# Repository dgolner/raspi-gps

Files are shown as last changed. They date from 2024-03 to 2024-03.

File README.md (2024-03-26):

English ∙ [Hrvatski](README-hr.md)

# raspi-gps

This simple project **raspi-gps** is a small GPS tracking system I made using Raspberry Pi and an external GPS Bluetooth module. This device is conceived as offline tracking, just connect it to a USB in the car, turn it on and record movement without connecting to the Internet. Since the movement (change of GPS position in time) is recorded in the form of GPX files on the SD card, it's possible to load such routes in external applications such as Google Earth by downloading from the SD card.

The project seemed interesting to me to share, so I created this tutorial.

## Contents of the project and tutorial

- [Motivation for this project](#motivation-for-this-project)
- [Components](#components)
- [Initial configuration of Raspberry Pi](#initial-configuration-of-raspberry-pi)
- [Raspberry Pi pairing and connecting to Bluetooth GPS module](#raspberry-pi-pairing-and-connecting-to-bluetooth-gps-module)
- [Python communication with Bluetooth GPS module](#python-communication-with-bluetooth-gps-module)
- [GPS codes](#gps-codes)
- [How to create a GPX file](#how-to-create-a-gpx-file)
- [Start a Python script automatically](#start-a-python-script-automatically)
- [Using button and RGB LED](#using-button-and-rgb-led)
- [Python code completion](#python-code-completion)
- [Project in practice](#project-in-practice)
- [Off-topic simplification with fewer components](#off-topic-simplification-with-fewer-components)
- [References](#references)

## Motivation for this project

Raspberry Pi is cool for personal projects and researching what can it do, so after some projects I did with Arduino, I went to something more powerful and more serious. Especially when it starts to think of gadgets that will use Wi-Fi with Bluetooth and program it in Python. From previously collected components in drawers, why not use what I have? I specifically have an old Raspberry Pi Zero W, an even older external GPS device, some electronic components from the starter kits and the idea.

I wanted to make a GPS tracker, but a little different one. The GPS module is not a classic Raspberry Pi component that connects to Raspberry pins. It's an external module with a battery and I can put it in a place where the GPS signal is stronger. That is why there are some advantages over GPS and tracking through cell phones and some special apps. So Raspberry Pi just connects to a USB or Power Bank, merges with GPS, finds visible satellites and starts tracking the position. It's a good idea to save routes on weekend rides. Online monitoring of such a route or current position can only be an upgrade over this project one day.

## Components

For this project, I'll use a Raspberry Pi Zero W just because I have it from before and it's compact enough for me. Any Raspberry that supports Wi-Fi and Bluetooth can be used. Wi-Fi is essential for connection to the PC, configuring, uploading Python code and downloading files from the SD card.

Bluetooth is used to connect to the external GPS module. In my case, I use ancient Haicom HI-406BT, so it's good to keep track of that mark in the tutorial in the part that refers to Bluetooth connection and communication. Almost every standalone Bluetooth GPS device that supports serial communication and NMEA data will serve a purpose. It doesn't matter if it's a premium model (I didn't try Garmin GLO 2 since it's too expensive for my needs) or some cheap noname (an even better option), it's important to find some that can be connected to PC, mobile phone or something third that supports Bluetooth, can pair and support serial communication. Support for Galileo or GLONASS doesn't matter, GPS support is essential, and for easier check of your device just see if it contains at least a SiRF StarIII chip.

Not necessary, but a Power Bank can be connected to Raspberry's USB port if it will not be suited otherwise, eg through USB in the car. Of the other components, there are some resistors, DuPont wires, connectors, a button, RGB LED and a small experimental breadboard, all for the compactness of the solution. The resistors are there for protection and can be of other resistance, not too big and will work OK.

 Components are listed in the table:

| **Used components** |
|---|
| 1x Raspberry Pi Zero W |
| 1x external Bluetooth GPS module |
| 1x powerbank |
| 1x mini breadboard |
| 1x button |
| 1x RGB LED |
| 1x 1 kΩ resistor |
| 2x 10 kΩ resistor |
| pin connectors and DuPont wires |

For the project, I used an RGB LED with a common anode (+ pole), which made it difficult for me to program, but that's the RGB LED that I had. Programming is easier with an LED with a common cathode (- pole). It's easier because the colors are turned on by releasing electricity on each pin in charge of color, for example, high on the red and low on others results only in the red color of the LED. When the LED has a common anode (+), colors are turned on by shutting down the current (sending low on pins), so it's inverted. For example, for red color, it means low on the pin for red and high on the others. If you have an RGB LED that is not like in my case, feel free to play a little for the results.

How the components are first drawn and interconnected on the diagram:

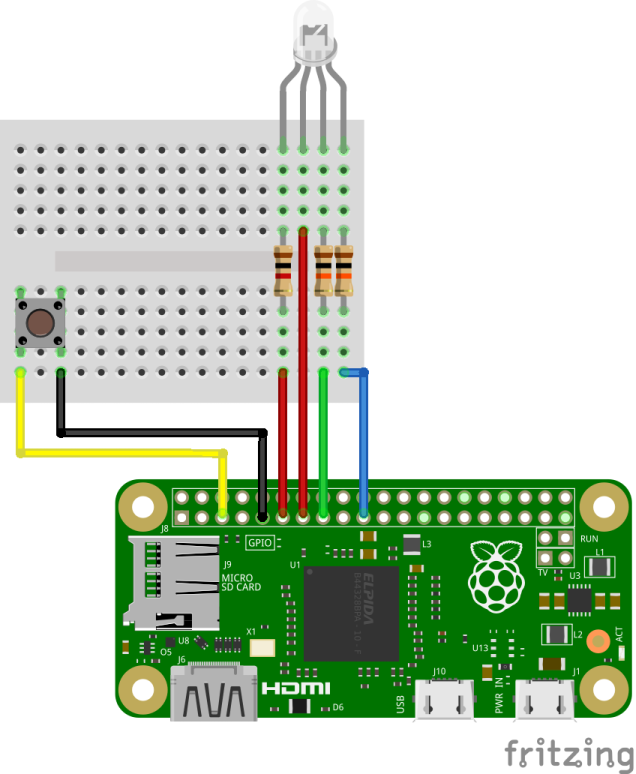
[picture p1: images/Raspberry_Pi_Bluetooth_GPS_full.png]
Fritzing diagram - Raspberry Pi Zero W with components


I use a 1 kΩ resistor on the red pin of the RGB LED while I use 10 kΩ resistors on the others. There is a resistor of lower value on the red to get better light intensity but feel free to play with the combinations of resistors.

This is how the components are connected in the project while still on the table:

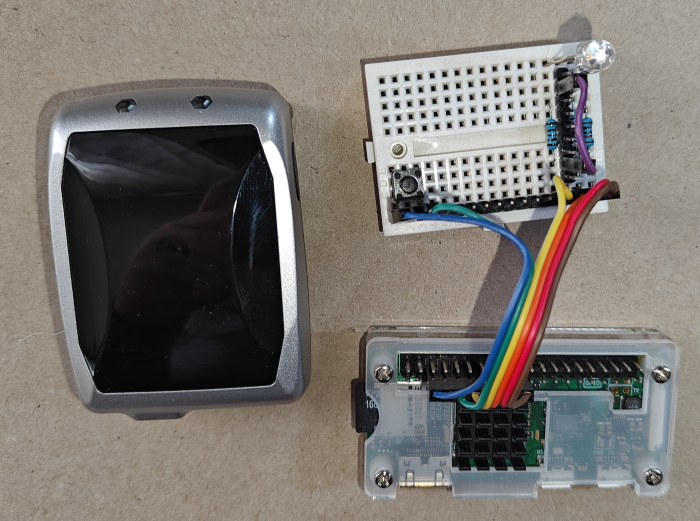
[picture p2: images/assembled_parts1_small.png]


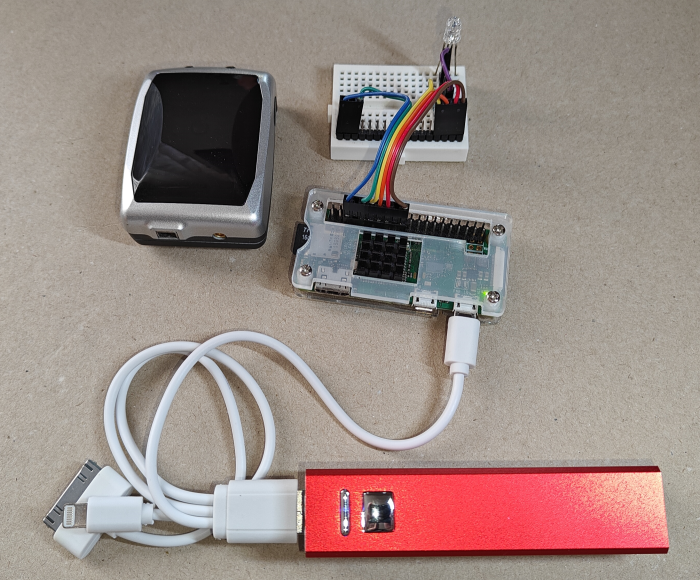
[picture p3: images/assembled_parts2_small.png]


After configuring, uploading Python code, local testing and packaging into a small case this is how my project looks in the car connected to a USB and the GPS device is located under the rear glass for a better reception of the satellites:

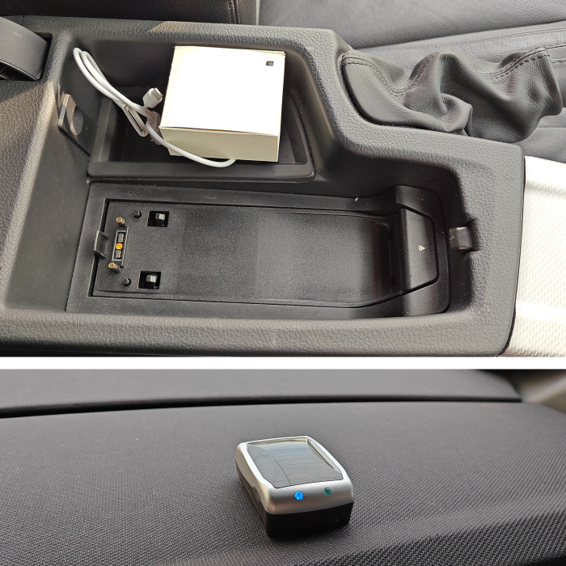
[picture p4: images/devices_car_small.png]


I made a cardboard mini case, so it can be downloaded, printed and cut, and fits the dimensions of the components I used.

[](/resources/RasPiGPS_cardboard.pdf)

Once the components are connected, it's necessary to configure the Raspberry Pi before programming.

## Initial configuration of Raspberry Pi

The Raspberry Pi OS has to be installed on the Raspberry Pi that will be used, I installed it over the Raspberry Pi Imager earlier, so it's not covered in this tutorial. It was also created when installing a **pi** user with a password. I don't use Raspberry when it's connected to the monitor, I configured it in headless mode. This can only complicate the work at first. It's important to configure which Wi-Fi network it connects to and which will be a fixed IP address.

To connect to Raspberry over the home Wi-Fi network, it's necessary on its SD card in the root directory to create an empty file **ssh** without extension:



Also on the SD card in the root directory create a file with the exact name **wpa_supplicant.conf** in which the Wi-Fi connection data will be stored. The contents of the file itself should be:
```sh
country=YOUR_COUNTRY_CODE
ctrl_interface=DIR=/var/run/wpa_supplicant GROUP=netdev
update_config=1
network={
    ssid="YOUR_WIFI_SSID"
    psk="YOUR_WIFI_PASSWORD"
    key_mgmt=WPA-PSK
}
```

Under **YOUR_COUNTRY_CODE** put your country code (eg us), under **YOUR_WIFI_SSID** put SSID of home Wi-Fi and in **YOUR_WIFI_PASSWORD** put your network password. It's obvious here that security is not at a high level, but at least Raspberry will connect automatically to the network after boot. The next thing after booting is finding its IP address, which can be found most often by connecting and checking on a home router.

The next step is to connect through its IP address using **Putty**, simply entering the SSH connection with the IP address of Raspberry Pi and when requested enter username and password. After connecting, you'll get the shell:

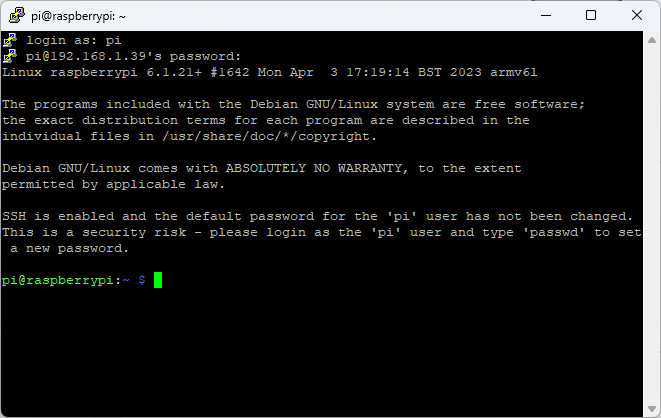
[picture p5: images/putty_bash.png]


From the shell, launch the configuration of Raspberry Pi OS:
```sh
sudo raspi-config
```

The Configuration Tool screen is obtained and be sure to set an autologin with user **pi** (set default user) for later automatic launch of the Python script of this project:

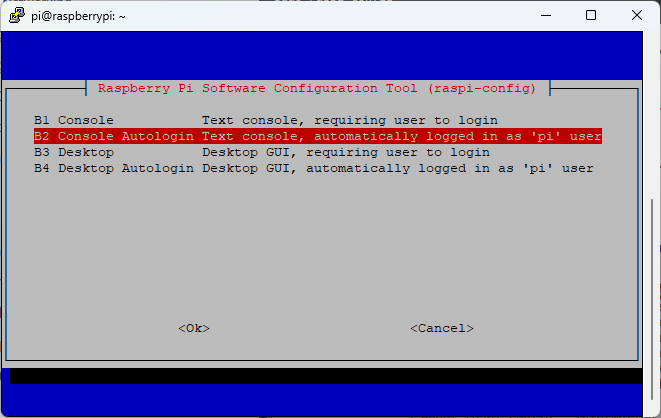
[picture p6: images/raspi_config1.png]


Also, be sure to enable SSH Server:

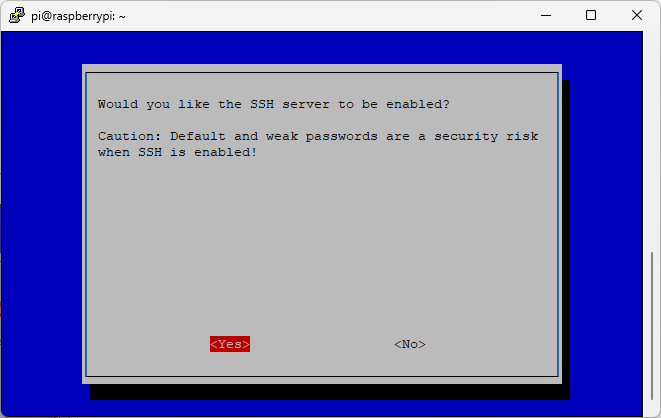
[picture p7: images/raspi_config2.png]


After leaving the raspi-config, it's necessary to set a static IP address so we don't have to look for it each time Raspberry connects to the router. For this, edit the file **/etc/dhcpcd.conf**, from various shell editors, I mostly use **pico**:
```sh
pico /etc/dhcpcd.conf
```

In the file, you need to locate the section where the static IP address is configured. Initially, all lines in the file are commented out with **#**. Uncomment the lines, following the example, and modify them according to your router’s address and the desired fixed IP address:
```sh
# Example static IP configuration:
interface eth0
static ip_address=<YOUR_RASPBERRY_IP>/24
#static ip6_address=fd51:42f8:caae:d92e::ff/64
static routers=<YOUR_ROUTER_IP>
static domain_name_servers=<YOUR_ROUTER_IP> 8.8.8.8
```
Replace **<YOUR_RASPBERRY_IP>** with the desired fixed address. It can even be the one under which the Raspberry initially connected to the router automatically. Replace **<YOUR_ROUTER_IP>** with the router’s IP address, such as 192.168.0.1 (which remains unchanged). Save the changes and exit the editor.

After making the changes, restart the Raspberry:
```sh
sudo shutdown -r now
```

To upload and download files (Python code, GPX files) on the Raspberry’s SD card while it’s connected to the network, it’s best and most practical to use the FTP protocol along with a free client like FileZilla. To achieve this, follow these steps for installing the FTP server from the shell:
```sh
sudo apt install vsftpd
```

After installation, proceed with configuring the FTP server by editing the file **/etc/vsftpd.conf**:
```sh
sudo pico /etc/vsftpd.conf
```

In the file, when you find these commented lines, uncomment them by removing the **#**
```sh
#write_enable=YES
#local_umask=022
#anon_upload_enable=YES
```

At the end of the file add the following lines:
```sh
user_sub_token=$USER
local_root=/home/$USER/FTP
```

Save changes, exit the editor and from shell create FTP shared directory **FTP/share** in your user home directory and add all rights to users:
```sh
mkdir -p /home/pi/FTP/share
chmod 777 /home/pi/FTP/share
```

Restart FTP daemon:
```sh
sudo service vsftpd restart
```

If everything is successful, you can connect to your Raspberry with an FTP client.

## Raspberry Pi pairing and connecting to Bluetooth GPS module

After the initial configuration, the GPS module checking and pairing with Raspberry Pi is followed and this step is crucial for going on. In the booting sequence of the Raspberry, Bluetooth service is also being launched, so the service status can be checked through the shell command:
```sh
systemctl status bluetooth
```

An active Bluetooth service is expected as in this example:
```sh
● bluetooth.service - Bluetooth service
     Loaded: loaded (/lib/systemd/system/bluetooth.service; enabled; vendor pre>
     Active: active (running) since Mon 2023-11-06 20:23:24 CET; 6 days ago
       Docs: man:bluetoothd(8)
   Main PID: 451 (bluetoothd)
     Status: "Running"
      Tasks: 1 (limit: 724)
        CPU: 327ms
     CGroup: /system.slice/bluetooth.service
             └─451 /usr/libexec/bluetooth/bluetoothd
```

After we checked and confirmed that the service is active now, it's necessary to start scanning for Bluetooth devices nearby. Of course, an external Bluetooth GPS device must be turned on. Finding devices nearby from the shell:
```sh
hcitool scan
```

The result of scanning should be a list of visible Bluetooth devices with their addresses and names, eg:
```sh
pi@raspberrypi:~ $ hcitool scan
Scanning ...
        00:02:78:19:70:30       HI-406BT
        4C:31:2D:73:88:88       MiTV-AYFR0
```

The use of **hcitool** is optional (it's good for control) because I'll continue with interactive tool **bluetoothctl** for pairing and scanning from the shell:
```sh
bluetoothctl
```

After starting, his interactive shell will appear through which the devices are managed:
```sh
Agent registered
[CHG] Controller B8:27:EB:F6:C0:3F Pairable: yes
[bluetooth]#
```

First "power on" Bluetooth from the tool:
```sh
[bluetooth]# power on
Changing power on succeeded
```

Register its agent:
```sh
[bluetooth]# agent on
Agent is already registered
```

Switch to a default agent:
```sh
[bluetooth]# default-agent
Default agent request successful
```

The previous steps were "fire and forget" because I just relied on the methods that surely worked. This is followed by scanning of the surrounding devices and monitoring what will appear as results (visible also through the previous use of **hcitool**):
```sh
[bluetooth]# scan on
Discovery started
[CHG] Controller B8:27:EB:F6:C0:3F Discovering: yes
[NEW] Device DB:93:F3:DA:E4:C0 vívoactive3
[NEW] Device 00:02:78:19:70:30 00-02-78-19-70-30
[CHG] Device 00:02:78:19:70:30 LegacyPairing: no
[CHG] Device 00:02:78:19:70:30 Name: HI-406BT
[CHG] Device 00:02:78:19:70:30 Alias: HI-406BT
[CHG] Device 00:02:78:19:70:30 LegacyPairing: yes
```

From the upper result, it's necessary to find the address of the Bluetooth GPS module according to its name and it's good to remember since it will be used several times throughout the tutorial. It's crucial to detect which GPS module you use since each is different. In my example from the components I used, I found 00:02:78:19:70:30 which corresponds to the name HI-406BT. So, in your case, find which address matches your device and pair it with the command **pair** followed by the address, this is my example:
```sh
[bluetooth]# pair 00:02:78:19:70:30
Attempting to pair with 00:02:78:19:70:30
[CHG] Device 00:02:78:19:70:30 Connected: yes
Request PIN code
[agent] Enter PIN code: 0000
[DEL] Device DB:93:F3:DA:E4:C0 vívoactive3
[CHG] Device 00:02:78:19:70:30 UUIDs: 00001101-0000-1000-8000-00805f9b34fb
[CHG] Device 00:02:78:19:70:30 ServicesResolved: yes
[CHG] Device 00:02:78:19:70:30 Paired: yes
Pairing successful
[CHG] Device 00:02:78:19:70:30 ServicesResolved: no
[CHG] Device 00:02:78:19:70:30 Connected: no
```

Immediately after attempting to pair, as seen above, you will need to enter your **PIN** pairing code, my example and a lot of them by default have **0000**. If everything has passed successfully you will see the message **Pairing successful**. When pairing, it's also possible to get this type of error:
```sh
[bluetooth]# pair 00:02:78:19:70:30
Attempting to pair with 00:02:78:19:70:30
Failed to pair: org.bluez.Error.AlreadyExists
```

> :warning: In this case, the most common problem is that the device is already connected to something and in use, so it needs to be disconnected from this other device. After that, repeat the upper steps. If that doesn't help, restarting of the Bluetooth service could help.

If everything has gone through so far, it's possible to get info about the device and status according to its address:
```sh
[bluetooth]# info 00:02:78:19:70:30
Device 00:02:78:19:70:30 (public)
        Name: HI-406BT
        Alias: HI-406BT
        Class: 0x00001f00
        Paired: yes
        Trusted: no
        Blocked: no
        Connected: no
        LegacyPairing: yes
        UUID: Serial Port               (00001101-0000-1000-8000-00805f9b34fb)
        RSSI: -35
```

Furthermore, all paired devices can be seen, most important is to see the GPS module that will be used in the project:
```sh
[bluetooth]# paired-devices
Device 00:02:78:19:70:30 HI-406BT
```

Finally, since everything went OK, you should exit from the **bluetoothctl** tool because it will no longer be needed:
```sh
[bluetooth]# exit
```

The next step is tool **rfcomm** also used in Bluetooth configuration through shell:
```sh
rfcomm
```

The result will be the address and status of **RFCOMM** channels to which the Bluetooth device is connected as my example:
```sh
rfcomm1: 00:02:78:19:70:30 channel 1 closed
```

It's important to remember the results from **rfcomm1** as it will be used below as part of the command. To connect to the device from the shell, it's necessary to combine **/dev/rfcomm1** and the address of the device from the previous steps:
```sh
rfcomm bind /dev/rfcomm1 00:02:78:19:70:30
```

> :warning:  If you have no rights, the following error will appear:

**Can't create device: Operation not permitted**

The solution is to use **sudo** to call the command:
```sh
sudo rfcomm bind /dev/rfcomm1 00:02:78:19:70:30
```

If we have successfully done all of these steps so far, which means we have already paired the device and we use it, we will get the following message that means everything is OK:
**Can't create device: Address already in use**

It looks like a warning or an error, but it's the result of the previous tools that are used. Later, that binding through **rfcomm1** will be used in Python scripts.

## Python communication with Bluetooth GPS module

It's time to write the first Python program that will communicate with the Bluetooth GPS module. The minimum version of Python should be 3.5, in my case it was used 3.9.2, but it's always good to use the higher version. Since communication through Bluetooth is a serial, first from shell check if there is a Python library **pyserial** that will be used:
```sh
pip3 list | grep pyserial
```

If the upper check doesn't return that the library exists, you should install it (if it shows an error with permissions, switch to **pi** user with **su pi**):
```sh
pip3 install pyserial
```

Now create a new Python file named **raspi-gps.py** that will read serial communication and print as meaningfully as possible. The serial communication reads data from the port located on device **/dev/rfcomm1** which corresponds to the previous chapter. It's important to know that this port will be further used, and the steps for connecting to Bluetooth from the previous chapter are also important. For this first script, it's mandatory to first connect to the GPS module before starting (see previous use of **rfcomm bind**). In an infinite loop, the script is trying to read character by character from the serial port until **'\r'** is found and then, that message is printed. Source code of this first iteration of connecting to the GPS module and serial communication:
```python
import serial

sr = serial.Serial('/dev/rfcomm1', timeout=2)
line = ''

while True:
  chr = sr.read().decode('utf-8')
  if chr == '\r':
    print(line)
    line = ''
  else:
    line = line + chr
```

After a short study of the source code, run it from the shell:
```sh
python3 raspi-gps.py
```

If everything went OK from the previous steps and there were no errors when running the Python script, the cryptic lines similar to my example should soon appear:
```sh
$GPVTG,202.93,T,,M,0.05,N,0.1,K,N*0C

$GPGGA,165941.553,4553.9397,N,01650.9875,E,1,03,2.6,-41.4,M,41.4,M,,0000*49

$GPRMC,165941.553,A,4553.9397,N,01650.9875,E,0.10,216.49,130923,,,A*62

$GPVTG,216.49,T,,M,0.10,N,0.2,K,N*09

$GPGGA,165942.553,4553.9396,N,01650.9875,E,1,03,2.6,-41.4,M,41.4,M,,0000*4B

$GPRMC,165942.553,A,4553.9396,N,01650.9875,E,0.09,252.51,130923,,,A*61

$GPVTG,252.51,T,,M,0.09,N,0.2,K,N*08

$GPGGA,165943.553,4553.9396,N,01650.9874,E,1,03,2.6,-41.4,M,41.4,M,,0000*4B

$GPRMC,165943.553,A,4553.9396,N,01650.9874,E,0.10,215.45,130923,,,A*6F

$GPVTG,215.45,T,,M,0.10,N,0.2,K,N*06
```

This looks completely correct and it's **NMEA** data coming from communication with the GPS module. Further, we'll deal with deciphering these data.

If an error occurs after starting this script and it's related to binding to the GPS module and is also visible as a Python exception, it means that it's necessary to restart the binding before starting this script from the shell. As in the previous steps you must run **rfcomm bind** with the device address (I'll continue to use **<YOUR_BLUETOOTH_MAC_ADDRESS>**) and check the status:
```sh
sudo rfcomm bind /dev/rfcomm1 <YOUR_BLUETOOTH_MAC_ADDRESS>
rfcomm
```

In order not to have to repeat the binding at each launch of Raspberry Pi and check the status before the start of a Python script, I added a call for binding immediately in the script. It will execute the binding by calling an OS command at each start of this script:
```python
import os
import serial
import sys
import time

try:
  fp = os.popen('sudo rfcomm bind /dev/rfcomm1 <YOUR_BLUETOOTH_MAC_ADDRESS>')
  time.sleep(2)
  fp.close()
except:
  print(sys.exc_info())
  sys.exit(1)

try:
  sr = serial.Serial('/dev/rfcomm1', timeout=2)
except:
  sys.exit(1)

line = ''

while True:
  try:
    chr = sr.read().decode('utf-8')
    if chr == '\r':
      print(line)
      line = ''
    else:
      line = line + chr
  except:      
    sys.exit(1)
```

Run again from the shell:
```sh
python3 raspi-gps.py
```

The result should be the same, the **NMEA** data of the GPS module will appear and less should be taken care of connecting to the module, it's enough to turn it on and after that, you can run the Python script that will begin to communicate with it.

## GPS codes

**NMEA** (National Marine Electronics Association) is as it says an association, and for is important **NMEA-0183** communication specification primarily intended for nautical electronics. Most importantly, it's used as a standard for communication with GPS devices. External GPS devices receive signals from visible satellites and form NMEA data that transmit further as in our case via Bluetooth serial communication. The data contain the talker ID (GPS, Galileo, GLONASS, BeiDou), message group and the data that correspond to the group. Details of the groups and message content with field descriptions are available in the link [NMEA Sentences](https://receiverhelp.trimble.com/alloy-gnss/en-us/NMEA-0183messages_MessageOverview.html).

Any message that is received (NMEA sentence) begins with **$** and talker ID, from the above example comes **$GP** which is a label for **GPS**. If your GPS module supports other systems, you could also get the start of a message for example with $GA as Galileo. I'll focus on GPS so I'll decode messages that start with **$GP**. After the talker ID comes the message group, and for this project, the most important are the **GGA - Global Positioning System Fix Data** and **VTG - Track made good and Ground speed**. GGA data contain various fields that are important to me: latitude, longitude, elevation and orientation, I won't use others. VTG is interesting to me just for reading the speed, I don't use the rest.

I extracted the necessary information according to the group and filed position in the message, it helped me NMEA documentation, and further, all that matters is the presentation of the data. There is a challenge with the value of the latitude and longitude because their values are slightly different from expectations, so it's necessary to convert from NMEA formatted data (format is (d)ddmm.mmmm where **d** stands for degrees, and **m** stands for minutes) to decimal format. I used a little help from an article on [Stack Overflow](https://stackoverflow.com/questions/36254363/how-to-convert-latitude-and-longitude-of-nmea-format-data-to-decimal) so I also created a conversion function in my Python code.

I've upgraded the upper Python code for reading the NMEA data. Every message that is read from GPS, regarding NMEA codes is extracted and checked if it contains the necessary GGA and VTG groups and the necessary values in them. To display the position, I additionally convert values to degrees and add the orientation. So upgraded and beautified Python source code looks now like this:
```python
import math
import os
import serial
import sys
import time

def nmeaToDeg(v):
  y, x = math.modf(v / 100)
  y = (y * 10) / 6
  return x + y

try:
  fp = os.popen('sudo rfcomm bind /dev/rfcomm1 <YOUR_BLUETOOTH_MAC_ADDRESS>')
  time.sleep(2)
  fp.close()
except:
  print(sys.exc_info())
  sys.exit(1)

try:
  sr = serial.Serial('/dev/rfcomm1', timeout=2)
except:
  sys.exit(1)

line = ''

while True:
  try:
    chr = sr.read().decode('utf-8')
    if chr == '\r':
      parts = line.replace('\n', '').split(',')

      try:
        # GGA - Global Positioning System Fix Data
        if parts[0] == '$GPGGA':
          latitude = nmeaToDeg(float(parts[2]))
          latitudeDirection = parts[3]
          longitude = nmeaToDeg(float(parts[4]))
          longitudeDirection = parts[5]
          print('Latitude / longitude: %s %s, %s %s' % 
            (latitude, latitudeDirection, longitude, longitudeDirection))
          elevation = float(parts[9])
          print('Elevation: %s m' % (elevation))

        # VTG - Track made good and Ground speed
        if parts[0] == '$GPVTG':
          speed = float(parts[7])
          print('Speed: %s km/h' % (speed))
      except:
        None

      line = ''
    else:
      line = line + chr
  except:
    print(sys.exc_info())
    sys.exit(1)
```

Run again from the shell:
```sh
python3 raspi-gps.py
```

The result should be a formatted output print of the current GPS position, elevation and speed if it's all successfully read.

## How to create a GPX file

After launching and testing this program, the next step is writing GPS positions in a file, we'll specifically use **GPX** format. **GPX** ([GPS Exchange Format](https://en.wikipedia.org/wiki/GPS_Exchange_Format)) is an XML schema for GPS data recording that can be used in other applications, and in this tutorial, we'll use it to write down the track. This results in the tracking of our Raspberry Pi device. The new unique **.gpx** file will always be created when launching the Python script. The reason for recording the change of location, and only if it occurs after 10 seconds is a reduction of file size, there is no need to write down the same position in the file or just any minimum change. These parameters can be manipulated, it just takes a small modification of the script.

To create **GPX** format in Python we will use the library **gpxpy** - [GPX File Parser](https://pypi.org/project/gpxpy/). First, you need to check if the library is installed:
```sh
pip3 list | grep gpxpy
```

If the upper check doesn't return the existence of the library (initially it's not installed), you should install it (if an error occurs that there are no user rights, switch to **pi** user with **su pi**) from the shell:
```sh
pip3 install gpxpy
```

The use of this library consists of creating an object and its tracks and segments containing points. Point is a single GPS position that we'll add to an object which we'll save in the GPX file. Since the position in the GPX object cannot be written exactly how we read it from communication and its NMEA messages, it needs to be adjusted a little bit. One step of adjustment is the very formatting of the position as I did it in the previous Python script, so I'll use it, followed by another addition. The orientation of the position (N, S, E, W) is a single field in the NMEA message, but in the GPX format, it's contained in geographical latitude and longitude. Therefore, orientations S and W are multiplied with -1 to convert them into GPX format. Also, an important thing is to write the exact time that must be in **ISO 8601** format.

In the below code, it can be seen that the script doesn't record speed in the GPX object. The reason is that by default, GPX version 1.1 is used in which speed is not supported. If a speed (for auto enthusiasts) needs to be written, the GPX 1.0 version should be used. That's a smaller adjustment, the speed value should be added to the end of the parameter list of the ```gpxpy.gpx.GPXTrackPoint``` as ```speed = speed``` and method call ```gpx.to_xml()``` should be replaced with ```gpx.to_xml(version="1.0")``` while the rest remains the same. For some can be an additional challenge that speed is read from the VTG message, and the rest of the data from the GGA message which is currently recorded.

The additional tiny functionality I added at the beginning of the Python script at execution refers to the reading of the arguments with which we start it. It can be of good use when preparing for pairing and starting communication with the GPS module. The addition is, that if a number is passed as an argument, the script will pause for so many seconds before continuing to work. This functionality will be used in the next chapter.

The new Python source code after the addition of the described functionalities:
```python
import datetime
import gpxpy
import math
import os
import serial
import sys
import time

def nmeaToDeg(v):
  y, x = math.modf(v / 100)
  y = (y * 10) / 6
  return x + y

# from argument set sleep
if len(sys.argv) > 1:
  time.sleep(int(sys.argv[1]))

try:
  fp = os.popen('sudo rfcomm bind /dev/rfcomm1 <YOUR_BLUETOOTH_MAC_ADDRESS>')
  time.sleep(2)
  fp.close()
except:
  print(sys.exc_info())
  sys.exit(1)

try:
  sr = serial.Serial('/dev/rfcomm1', timeout=2)
except:
  sys.exit(1)

line = ''

# GPX object, track, segment
gpx = gpxpy.gpx.GPX()
gpx.name = 'Raspberry Pi GPS'
gpx.description = 'GPS track'
gpx_track = gpxpy.gpx.GPXTrack()
gpx.tracks.append(gpx_track)
gpx_segment = gpxpy.gpx.GPXTrackSegment()
gpx_track.segments.append(gpx_segment)

t0 = None
lat0 = 0
lon0 = 0
file_name = datetime.datetime.now().strftime('%Y%m%dT%H%M%S') + '.gpx'

while True:
  try:
    chr = sr.read().decode('utf-8')
    if chr == '\r':
      parts = line.replace('\n', '').split(',')

      try:
        # GGA - Global Positioning System Fix Data
        if parts[0] == '$GPGGA':
          latitude = nmeaToDeg(float(parts[2]))
          latitudeDirection = parts[3]
          longitude = nmeaToDeg(float(parts[4]))
          longitudeDirection = parts[5]
          print('Latitude / longitude: %s %s, %s %s' % 
            (latitude, latitudeDirection, longitude, longitudeDirection))
          elevation = float(parts[9])
          print('Elevation: %s m' % (elevation))
          if t0 == None:
            t0 = datetime.datetime.now()
          else:
            t1 = datetime.datetime.now()
            # record every 10 seconds
            if (t1 - t0).total_seconds() > 10 and lat0 != latitude and lon0 != longitude:
              t0 = t1
              lat0 = latitude
              lon0 = longitude
              if latitudeDirection == 'S':
                latitude = latitude * (-1)
              if longitudeDirection == 'W':
                longitude = longitude * (-1)
              gpx_segment.points.append(gpxpy.gpx.GPXTrackPoint(
                latitude = latitude, 
                longitude = longitude, 
                elevation = elevation, 
                time = t1))
              file = open(file_name, 'w')
              file.write(gpx.to_xml())
              file.close()

        # VTG - Track made good and Ground speed
        if parts[0] == '$GPVTG':
          speed = float(parts[7])
          print('Speed: %s km/h' % (speed))
      except:
        None

      line = ''
    else:
      line = line + chr
  except:
    print(sys.exc_info())
    sys.exit(1)
```

Run from the shell:
```sh
python3 raspi-gps.py
```

The result should be the same as in the previous Python code, and in the same directory, it'll also be created **.gpx** file whose size will increase as the GPS position change is recorded.

## Start a Python script automatically

Now the Python script is already completed, so it could be automatically run every time after boot of a Raspberry Pi instead of manually starting. Manual starting is fine when you program locally and test like this, but in real life, it must be automatically run as soon as possible. To add automatic starting after booting, it's necessary to edit the file **/etc/rc.local**, I'll use pico again:
```sh
sudo pico /etc/rc.local
```

It's necessary to position before line **exit 0** and add the following lines:
```sh
cd /home/pi/FTP/share
sudo -u pi python3 raspi-gps.py 30 > log.txt 2>&1 &
```

In my case file now looks like this:

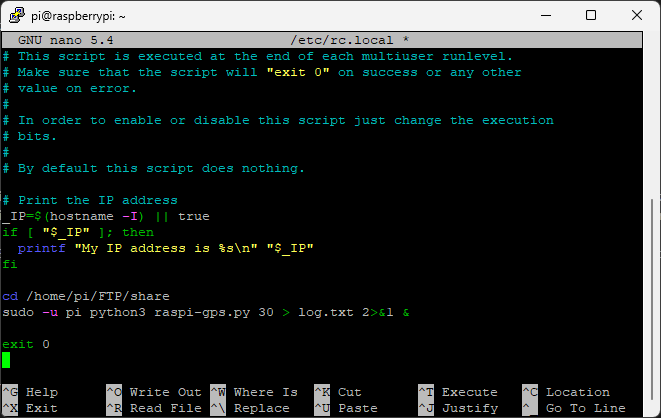
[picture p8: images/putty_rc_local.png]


With this change, we are first positioning in the directory where the Python script is located. After that, under the user **pi** (this is required) a Python script **raspi-gps.py** is started with a 30-second waiting parameter (which should be enough to start all the services on which it depends), output messages of the script are forwarded to the log file **log.txt** so that errors can be seen in it, and at the end of the whole row there is a mandatory sign **&** that launches the process in the background.

I mentioned the 30-second waiting parameter in the previous chapter and refers to this part of the Python code, so if another number is passed, for that many seconds it'll wait to continue for execution:
```python
# from argument set sleep
if len(sys.argv) > 1:
  time.sleep(int(sys.argv[1]))
```

After saving the changes of file **/etc/rc.local**, it's necessary to restart Raspberry Pi from the shell:
```sh
sudo shutdown -r now
```
or
```sh
sudo reboot
```

With that and if everything went OK, the Python script will be automatically launched. If errors occurs, they're visible in the same directory in file **log.txt**.

It's also important to mention, that after successfully launching, if we connect to Raspberry Pi with Putty and change the script, before the next start of it, it's necessary to kill the existing process. How to check whether the script is running using the shell:
```sh
ps -fu pi | grep raspi-gps
```

According to the result, just find ```<pid>``` of the active process and from the shell call ```kill <pid>``` of that process.

## Using button and RGB LED

So far, the basis of the GPS tracker has been made, which can be used as it is, but then there is no interaction. It's time to make use of the button which is, in this project the only form of interaction together with RGB LED signaling by Raspberry Pi. For this purpose, we'll create a new Python file **gpio_test.py** which will try to work with the connected button and turn on and off RGB LED in various colors.

We saw the way of connecting the button and RGB LED with the Raspberry Pi at the beginning of the chapter [Components](#components). The components are connected to the Raspberry Pi voltage pin, ground pin and general-purpose pins. Pinout and the purpose of each pin can be seen at the link [Raspberry Pi Pinout](https://pinout.xyz/) or from the shell:
```sh
pinout
```

I chose pins that suit me according to the layout, in your version of the project you can also use some others with some changes in the code. In this testing script, I'll use the **GPIO3** pin to read if the button is pressed, the **GPIO17** pin for the red color of the RGB LED, the **GPIO22** pin for green and the **GPIO10** pin for blue. I will also use the **GPIO27** pin for voltage.

For managing GPIO pins I'll use **gpiozero** interface which should already be installed as part of Python in the Raspberry OS. I'll use its Button, LED and RGBLED classes and each of them will assign management of a particular pin. Programming is relatively simple and intuitive, it consists of turning on / off individual pins or reading the state of a button on the pin. Source code **gpio_test.py** that manages a button and RGB LED looks like this:
```python
import datetime
from gpiozero import Button, LED, RGBLED
import time

button = Button(3) # GPIO3
led = RGBLED(red = 17, green = 22, blue = 10) # red GPIO17, green GPIO22, blue GPIO10
power = LED(27) # GPIO27

power.on()
led.color = (0, 1, 1)
print('red')
time.sleep(2)
led.color = (1, 0, 1)
print('green')
time.sleep(2)
led.color = (1, 1, 0)
print('blue')
time.sleep(2)
led.color = (1, 1, 1)

t0 = 0

while True:

  if button.is_pressed:
    print('pressed')
    t1 = datetime.datetime.now()
    if t0 == 0:
      t0 = t1
    if (t1 - t0).total_seconds() > 5:
      led.color = (0, 1, 1)
      print('red')
      time.sleep(1)
      led.color = (1, 1, 1)
      t0 = 0
    else:
      led.color = (0, 0, 1)
      print('yellow')
      time.sleep(1)
      led.color = (1, 1, 1)
  else:
    t0 = 0
    led.color = (1, 0, 1)
    print('green')
    time.sleep(1)
    led.color = (1, 1, 1)

  try:
    time.sleep(1)

  except:
    print(sys.exc_info())
    led.color = (0, 1, 1)
    print('red')
    time.sleep(2)
    led.color = (1, 1, 1)
    power.off()
    sys.exit(1)
```
[][def-gpio_test.py]

After a little studying of what and how this source code works, it should be launched from the shell:
```sh
python3 gpio_test.py
```

In initialization, each class is assigned with individual pins. Immediately for two seconds, the RGB LED should be turned on red, green and blue. How to use the RGBLED class depends on the RGB LED used, I used the one with a common anode (+). In that case, the voltage is released to a single pin that manages the color. After turning on every color from above, the program checks the status of the button, if it's pressed for more than 5 seconds RGB LED will turn on red, shorter than that will turn on yellow, and if the button isn't pressed it will turn on green. After one second, the next iteration of the loop goes. Just in case, the status of a pressed button and which color is turned on will print when running.

## Python code completion

In this chapter, all previous versions of Python scripts are combined in one final Python source code of the project, it's the one that manages the Bluetooth, GPS module, button and RGB LED.

In addition, I'll take the opportunity to abstract some functionalities into classes and add some new functions. I created a new class **Color** as an enumeration for turning on individual colors on RGB LED. I separated creating and writing a route into a new class **Recorder**. For unexpected termination of the program, I further made a function **terminate** and to shut down the Raspberry Pi I made a function **shutdown**. I added a new large block of code for managing the detection of button presses and depending on the length of the pressure the statuses of the start and stop of the route recording are changed with the LED signaling. I also added a new functionality of shutting down the entire Raspberry Pi using the long button press. There is a short user manual under the source code.

The final completed source code of **raspi-gps.py** now looks like this:
```python
import datetime
from enum import Enum
from gpiozero import Button, LED, RGBLED
import gpxpy
import math
import os
import serial
import sys
import time

class Color(Enum):
  RED = (0, 1, 1)
  GREEN = (1, 0, 1)
  BLUE = (1, 1, 0)
  NONE = (1, 1, 1)

class Recorder:
  def __init__(self):
    self.recording = False
    self.__file_name = datetime.datetime.now().strftime('%Y%m%dT%H%M%S') + '.gpx'
    # GPX object, track, segment
    self.__gpx = gpxpy.gpx.GPX()
    self.__gpx.name = 'Raspberry Pi GPS'
    self.__gpx.description = 'GPS track'
    self.__gpx_track = gpxpy.gpx.GPXTrack()
    self.__gpx.tracks.append(self.__gpx_track)
    self.__gpx_segment = gpxpy.gpx.GPXTrackSegment()
    self.__gpx_track.segments.append(self.__gpx_segment)

  def addPoint(self, latitude, longitude, elevation, time):
    self.__gpx_segment.points.append(gpxpy.gpx.GPXTrackPoint(
      latitude = latitude, 
      longitude = longitude, 
      elevation = elevation, 
      time = time))
    self.write()

  def write(self):
    file = open(self.__file_name, 'w')
    file.write(self.__gpx.to_xml())
    file.close()

def nmeaToDeg(v):
  y, x = math.modf(v / 100)
  y = (y * 10) / 6
  return x + y

def terminate():
  led.color = Color.RED.value
  time.sleep(2)
  led.color = Color.NONE.value
  power.off()
  sys.exit(1)

def shutdown():
  track.write()
  led.color = Color.NONE.value
  power.off()
  os.system('sudo shutdown now')

# button connected to GPIO3
button = Button(3)
# LED pins: red GPIO17, green GPIO22, blue GPIO10
led = RGBLED(red = 17, green = 22, blue = 10)
# power pin on GPIO27
power = LED(27)
power.on()
led.color = Color.BLUE.value

# from argument set sleep
if len(sys.argv) > 1:
  time.sleep(int(sys.argv[1]))

try:
  fp = os.popen('sudo rfcomm bind /dev/rfcomm1 <YOUR_BLUETOOTH_MAC_ADDRESS>')
  time.sleep(2)
  fp.close()
except:
  print(sys.exc_info())
  terminate()

try:
  sr = serial.Serial('/dev/rfcomm1', timeout=2)
except:
  terminate()

led.color = Color.NONE.value
line = ''

t0 = None
lat0 = 0
lon0 = 0
tb0 = None
statusChanged = False
track = Recorder()

while True:
  try:
    if button.is_pressed:
      tb1 = datetime.datetime.now()
      if tb0 == None:
        tb0 = tb1
      td = (tb1 - tb0).total_seconds()
      if td > 10:
        led.color = Color.RED.value
        time.sleep(2)
        shutdown()
      else:
        if td < 0.5:
          # green for start recording, red for stop
          if track.recording:
            led.color = Color.RED.value
          else:
            led.color = Color.GREEN.value
        else:
          if not statusChanged:
            statusChanged = True
            if track.recording:
              track.write()
              track.recording = False
            else:
              track = Recorder()
              track.recording = True
            led.color = Color.NONE.value
    else:
      if tb0 != None:
        tb0 = None
        statusChanged = False
        led.color = Color.NONE.value

    chr = sr.read().decode('utf-8')
    if chr == '\r':
      parts = line.replace('\n', '').split(',')

      try:
        # GGA - Global Positioning System Fix Data
        if parts[0] == '$GPGGA':
          latitude = nmeaToDeg(float(parts[2]))
          latitudeDirection = parts[3]
          longitude = nmeaToDeg(float(parts[4]))
          longitudeDirection = parts[5]
          print('Latitude / longitude: %s %s, %s %s' % 
            (latitude, latitudeDirection, longitude, longitudeDirection))
          elevation = float(parts[9])
          print('Elevation: %s m' % (elevation))
          if track.recording:
            if t0 == None:
              t0 = datetime.datetime.now()
            else:
              t1 = datetime.datetime.now()
              # record every 10 seconds
              if (t1 - t0).total_seconds() > 10 and lat0 != latitude and lon0 != longitude:
                led.color = Color.GREEN.value
                t0 = t1
                lat0 = latitude
                lon0 = longitude
                if latitudeDirection == 'S':
                  latitude = latitude * (-1)
                if longitudeDirection == 'W':
                  longitude = longitude * (-1)
                track.addPoint(
                  latitude = latitude, 
                  longitude = longitude, 
                  elevation = elevation, 
                  time = t1)
                led.color = Color.NONE.value
          else:
            t0 = None
            lat0 = 0
            lon0 = 0

        # VTG - Track made good and Ground speed
        #if parts[0] == '$GPVTG':
        #  speed = float(parts[7])
        #  print('Speed: %s km/h' % (speed))
      except:
        led.color = Color.RED.value
        time.sleep(0.1)
        led.color = Color.NONE.value
        time.sleep(0.5)

      line = ''
    else:
      line = line + chr
  except:
    print(sys.exc_info())
    terminate()
```
[][def-raspi-gps.py]

After studying the source code for a bit, it should be launched from the shell, but now because of complexity it's good to check the syntax first as a new step before running:
```sh
python3 -m py_compile raspi-gps.py
python3 raspi-gps.py
```

Now the program will start signaling its work.

RGB LED turns blue for connecting to the GPS module. If an error occurs during this process, the LED turns red for 2 seconds and the program exits with its execution. In that case, there is no other solution than to look at the **FTP/share** directory log to see errors. Such errors should have been also visible earlier during the testing. Otherwise, if everything went OK in the previous steps of the tutorial, further problems are not expected.

When the GPS module has been successfully paired with Raspberry, the program occasionally gives some additional signals. While recording the route if the position changes every 10 seconds, the LED with turn green. If it's not completely positioned towards the satellites and doesn't read the position correctly, it will turn red. Pressing the button while not recording the route, the LED will turn green. Just keep the button pressed for 0.5 seconds to start recording the route. Otherwise, while program records the route, pressing the button will turn red. Holding a button for 0.5 seconds while recording; will stop recording the route. That's why the same button is for on/off mode, so on will turn LED green and off will turn red.

Each recording is saved as a separate **.gpx** file in the directory **FTP/share** and it can be downloaded and opened in a standalone software such as Google Earth for a visual examination of the route. For terminating this Python program, but also shut down the whole Raspberry, it's necessary to keep the button pressed for 10 seconds, which will signal with the LED turned in red. When you want to restart, repeat all the previous steps or physically turn on Raspberry.

And those are the instructions for using it. :smiley:

## Project in practice

After testing the whole system at home and on the PC, it's time to use it in real conditions, in my case in driving one route. By connecting the Raspberry to the car's USB or Power Bank, it starts to boot and then immediately launches the Python script. So when Raspberry boots, it's necessary to immediately turn on the external GPS module for pairing with Bluetooth and try to position it as soon as possible according to visible satellites. After that, it's up to you when to start and stop route recording using the button according to the manual from the previous chapter.

One of my recorded routes is in this example:

[][def-gpx-sample]

I opened the **.gpx** file in Google Earth and its picture is below. The tool is intuitive enough, so after loading the route and its drawing, some additional buttons on its interface will appear.

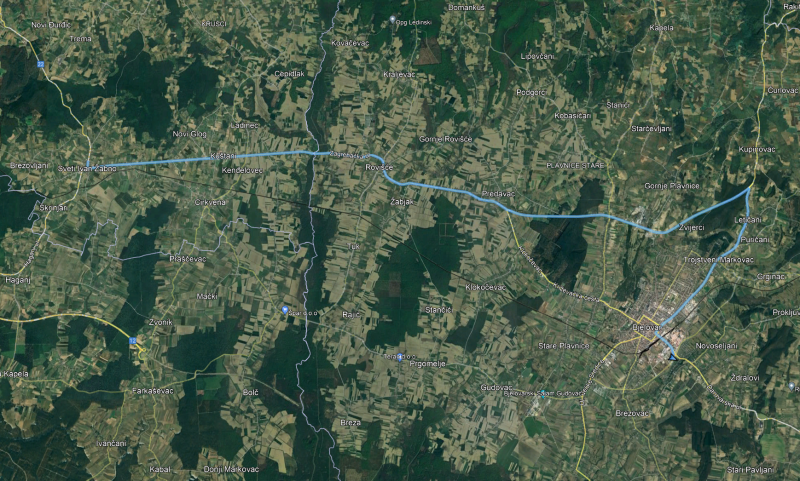
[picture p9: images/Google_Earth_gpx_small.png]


## Off-topic simplification with fewer components

If Raspberry Pi Zero W is used as in my case and you want to simplify this project by the reduction of the number of components, the internal LED of Raspberry could be used instead of RGB LED on the breadboard. Further, if you won't use resistors and DuPont wires, you'll end up just connecting the button to Raspberry as in this minimal diagram:

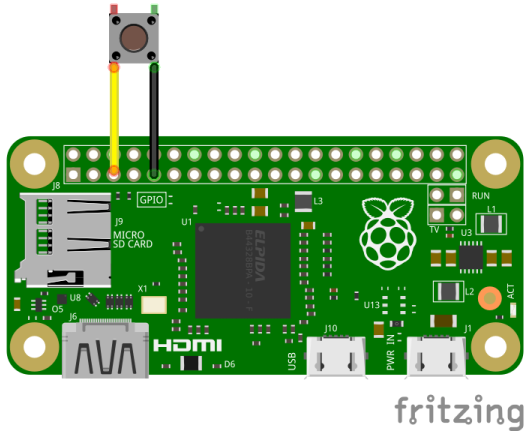
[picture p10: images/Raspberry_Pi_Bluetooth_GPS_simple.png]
Fritzing diagram - Raspberry Pi Zero W with minimum set of components


It looks ascetic and extremely compact, and turning on and off of an internal LED is possible with a little hack of using shell commands. It's about writing high (1) or low (0) values in the file **/sys/class/leds/mmc0/brightness** which is not possible for ordinary users, so we will use **sudo**.

Turning on the internal LED from the shell:
```sh
sudo sh -c "echo 1 > /sys/class/leds/mmc0/brightness"
```
Turning off the internal LED from the shell:
```sh
sudo sh -c "echo 0 > /sys/class/leds/mmc0/brightness"
```
If it fails from the first attempt, just start the commands again from the shell.

How to turn on and off the internal LED with a button and program it as a simple Python script? Below is the implementation that uses shell commands from Python, the calls of sending high and low values are first tried, and then the pressure of the button on the GPIO3 pin is monitored. Holding down the button for 5 seconds turns on the LED for a second and then it turns it off.

Create a new file **internal_led_test.py** with this source code:
```python
import datetime
from gpiozero import Button
import os
import time

button = Button(3) # GPIO3

os.system('sudo sh -c "echo 1 > /sys/class/leds/mmc0/brightness"')
time.sleep(2)
os.system('sudo sh -c "echo 0 > /sys/class/leds/mmc0/brightness"')

t0 = 0

while True:

  if button.is_pressed:
    print('pressed')
    t1 = datetime.datetime.now()
    if t0 == 0:
      t0 = t1
    if (t1 - t0).total_seconds() > 5:
      os.system('sudo sh -c "echo 1 > /sys/class/leds/mmc0/brightness"')
      time.sleep(1)
      os.system('sudo sh -c "echo 0 > /sys/class/leds/mmc0/brightness"')
      t0 = 0
  else:
    t0 = 0

  time.sleep(1)
```
[][def-internal_led_test.py]

Run this Python script from the shell:
```sh
python3 internal_led_test.py
```

If everything is OK, with a little intervention in source code you can relatively easily upgrade **raspi-gps.py** to make Raspberry work with an internal LED. :yum:

## References

- [Headless Raspberry Pi Setup](https://learn.sparkfun.com/tutorials/headless-raspberry-pi-setup/wifi-with-dhcp)
- [Raspberry Pi Configuration](https://www.raspberrypi.com/documentation/computers/configuration.html)
- [Raspberry Pi Hardware](https://www.raspberrypi.com/documentation/computers/raspberry-pi.html)
- [Raspberry Pi Pinout](https://pinout.xyz/)
- [NMEA Sentences](https://receiverhelp.trimble.com/alloy-gnss/en-us/NMEA-0183messages_MessageOverview.html)
- [GPS Exchange Format](https://en.wikipedia.org/wiki/GPS_Exchange_Format)
- [GPX File Parser](https://pypi.org/project/gpxpy/)
- [Physical Computing with Python](https://projects.raspberrypi.org/en/projects/physical-computing/0)

<!----------------------------------------------------------------------------------------------------------------->

[def-gpio_test.py]: /scripts/gpio_test.py
[def-raspi-gps.py]: /scripts/raspi-gps.py
[def-internal_led_test.py]: /scripts/internal_led_test.py
[def-gpx-sample]: /resources/20231026T195728.gpx

[Download Icon]: https://img.shields.io/badge/Download-37a779?style=for-the-badge&logoColor=white&logo=DocuSign

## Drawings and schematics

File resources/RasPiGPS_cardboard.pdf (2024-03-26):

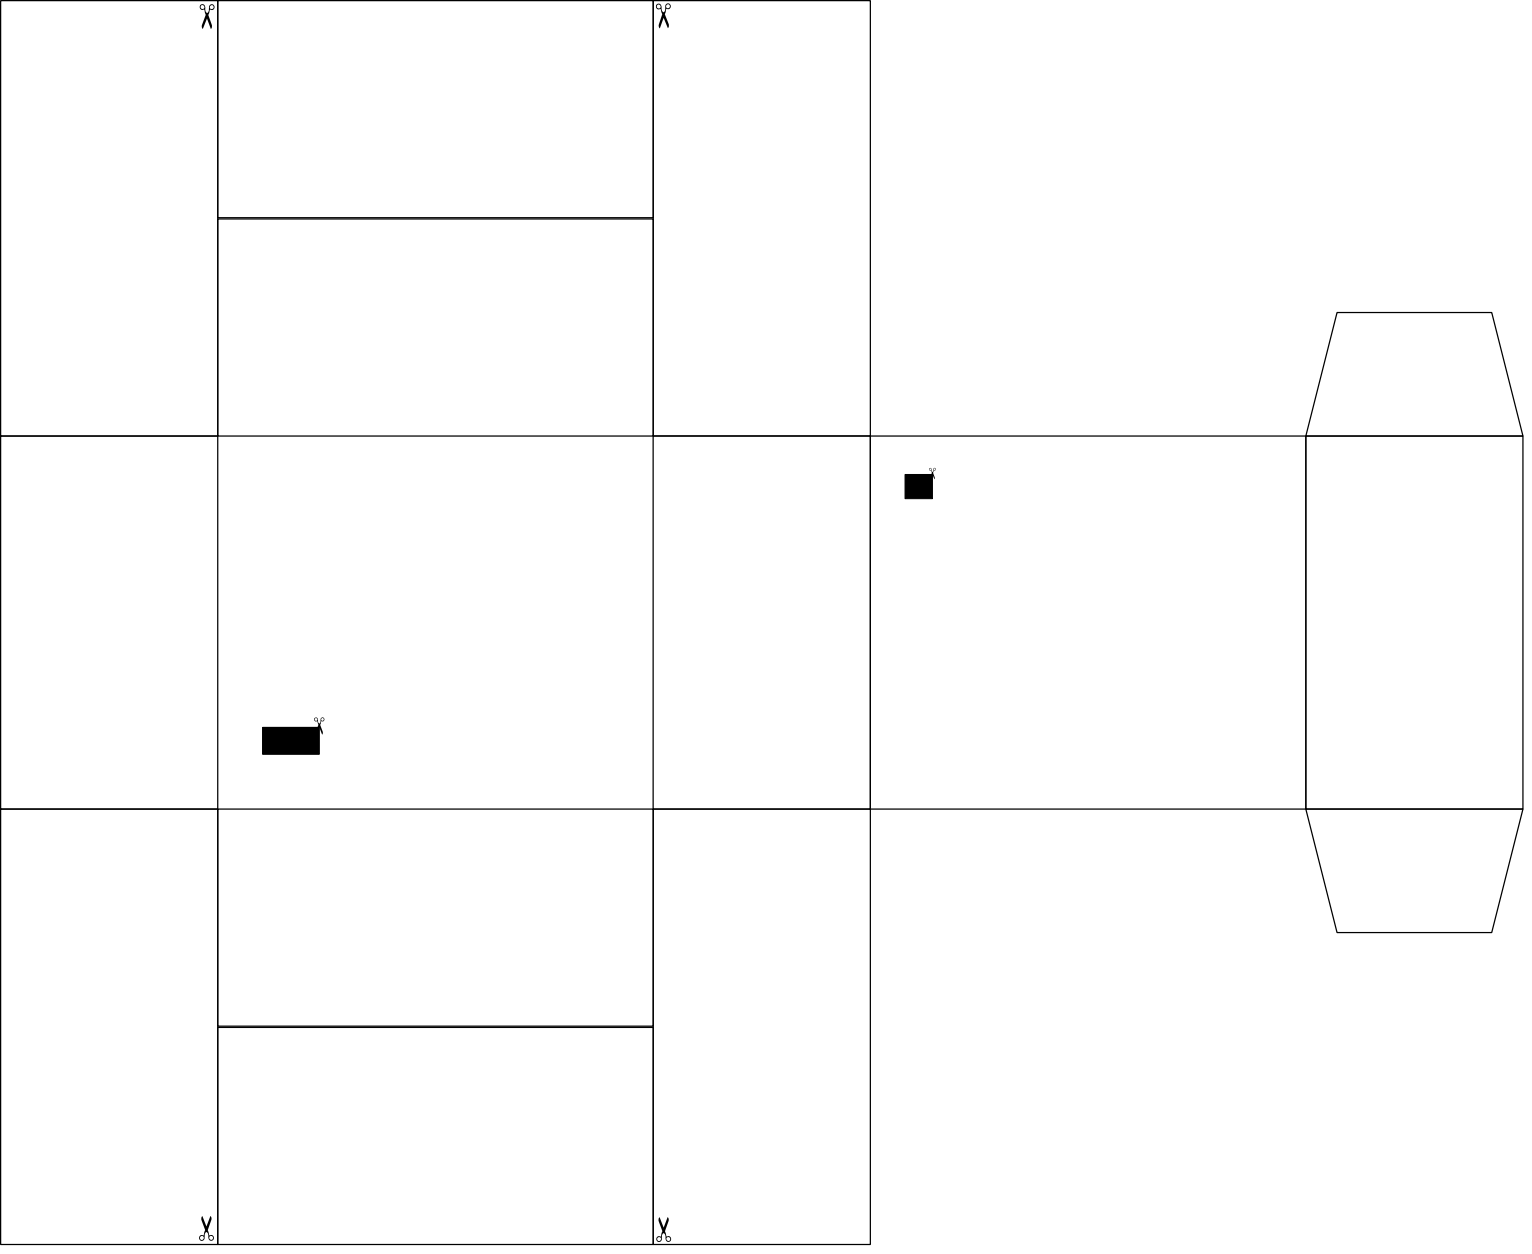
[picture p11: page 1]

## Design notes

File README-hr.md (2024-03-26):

[English](README.md) ∙ Hrvatski

# raspi-gps

Ovaj jednostavni projekt **raspi-gps** je mali GPS tracking sustav koji sam napravio koristeći Raspberry Pi i eksterni GPS Bluetooth modul. Ovakav uređaj je zamišljen kao offline tracking, odnosno samo se spoji na USB u npr. autu, upali i bilježi se kretanje bez spajanja na Internet. Pošto se kretanje (promjena GPS pozicije u vremenu) bilježi u obliku GPX fileova na SD kartici, po downloadu s SD kartice moguće je takve rute kretanja učitati u vanjsku aplikaciju kao što je Google Earth.

Projekt mi se učinio zanimljivim za podijeliti pa sam iz njega kreirao i daljnji tutorial.

## Sadržaj projekta i tutoriala

- [Motivacija za izradu projekta](#motivacija-za-izradu-projekta)
- [Komponente](#komponente)
- [Inicijalno konfiguriranje Raspberry Pi-ja](#inicijalno-konfiguriranje-raspberry-pi-ja)
- [Raspberry Pi uparivanje i spajanje Bluetooth GPS modula](#raspberry-pi-uparivanje-i-spajanje-bluetooth-gps-modula)
- [Python komunikacija s Bluetooth GPS modulom](#python-komunikacija-s-bluetooth-gps-modulom)
- [GPS kodovi](#gps-kodovi)
- [Kreiranje GPX filea](#kreiranje-gpx-filea)
- [Automatsko pokretanje Python skripte](#automatsko-pokretanje-python-skripte)
- [Korištenje gumba i RGB LED-ice](#korištenje-gumba-i-rgb-led-ice)
- [Kompletiranje Python koda](#kompletiranje-python-koda)
- [Projekt u živom radu](#projekt-u-živom-radu)
- [Off topic pojednostavljenje s manje komponenti](#off-topic-pojednostavljenje-s-manje-komponenti)
- [Reference](#reference)

## Motivacija za izradu projekta

Raspberry Pi je cool za osobne projekte i istraživanje što sve može pa nakon nekih projekata koje sam radio s Arduinom krenuo sam na nešto moćnije i ozbiljnije. Pogotovo kad se krene u smišljanje gadgeta koji će koristiti Wi-Fi, Bluetooth i još k tome sve isprogramirati u Pythonu. Od ranije skupljenih komponenti po ladicama zašto ne iskoristiti ono što imam? Konkretno imam dosta stari Raspberry Pi Zero W, još stariji samostalni eksterni GPS uređaj, nešto elektroničkih komponenti iz starter kitova i ideju.

Želio sam napraviti GPS tracker, ali malo drugačiji. GPS modul nije neki klasičan kao komponenta koja se spaja na pinove Raspberryja nego eksterni s vlastitom baterijom i kojeg mogu staviti na neko mjesto gdje će bolje hvatati GPS signal. Zato ima i neke prednosti pred GPS-om i trackingom preko mobitela i neke posebne aplikacije. Raspberry Pi se onda samo spoji na USB ili powerbank, upali i kad se spoji s GPS-om, ulove vidljivi sateliti praćenje pozicije može započeti. Dobra je primjena spremanje rute na vikend vožnjama. Online praćenje takve rute ili trenutnog položaja može biti samo nadogradnja jednog dana nad ovim projektom.

## Komponente

Za ovaj projekt osnova mi je Raspberry Pi Zero W samo zato što ga imam od prije i što mi je dovoljno kompaktan. Može se koristiti bilo koji Raspberry koji podržava Wi-Fi i Bluetooth. Wi-Fi je bitan zbog spajanja na PC, konfiguriranje, upload Python koda i download fileova s SD kartice.

Bluetooth se koristi za spajanje na eksterni GPS modul. U mom slučaju koristim prastari Haicom HI-406BT pa je dobro pratiti tu oznaku u dijelu tutoriala koji se odnosi na Bluetooth spajanje i komunikaciju. Gotovo svaki samostalni Bluetooth GPS uređaj koji podržava serijsku komunikaciju i NMEA podatke poslužit će svrsi. Nije bitno radi li se o nekom premium modelu (nisam probao Garmin GLO 2 pošto je preskup za moje potrebe) ili nekom jeftinom no name (čak bolja opcija), bitno pronaći neki koji se može spojiti na PC, mobitel ili nešto treće što podržava Bluetooth, može se upariti i podržava serijsku komunikaciju. Nije bitna podrška za Galileo ili GLONASS, bitna je podrška za GPS, a za lakšu provjeru uređaja dovoljno gledati sadrži li najmanje SiRF StarIII čip.

Nije nužan, ali dobro dođe powerbank spojen na Raspberryjev USB port ako se neće drugačije napajati, npr. preko USB-a u autu. Od ostalih komponenti tu je nešto otpornika, žica, konektora, gumb, RGB LED-ica i mala eksperimentalna pločica, isto zbog kompaktnosti rješenja. Otpornici su tu zbog zaštite te mogu biti i nekog drugog otpora, ne prevelikog i radit će ok.

Ugrubo su komponente popisane u tablici:

| **Korištene komponente** |
|---|
| 1x Raspberry Pi Zero W |
| 1x eksterni Bluetooth GPS modul |
| 1x powerbank |
| 1x mini eksperimentalna pločica |
| 1x gumb |
| 1x RGB LED |
| 1x 1 kΩ otpornik |
| 2x 10 kΩ otpornik |
| pin konektori i žice |

Za projekt sam koristio RGB LED-icu sa zajedničkom anodom (+ pol) što mi je malo otežalo programiranje, ali takvu sam imao. Lakše je programiranje kada je takva LED-ica sa zajedničkom katodom (- pol). Lakše je pošto se tada boje pale puštanje struje na pojedini pin zadužen za boju, npr. high na pinu za crvenu i low na ostalima rezultira samo crvenom bojom LED-ice. Kada se radi o zajedničkoj anodi (+), boje se pale zapravo gašenjem struje, odnosno inverzno je. Tako npr. za crvenu boju znači low na pinu za crvenu, a high na ostalim. Ako imate RGB LED-icu koja eto nije kao u mom slučaju slobodno se poigrajte malo za rezultate.

Kako su komponente prvo nacrtane i međusobno spojene na dijagramu:

Fritzing dijagram - Raspberry Pi Zero W s komponentama

Na crvenom pinu RGB LED-ice koristim otpornik od 1 kΩ dok na drugima koristim 10 kΩ otpornik. Na crvenom je manji zbog dobivanja intenziteta svjetla, ali slobodno se poigrajte s kombinacijama otpornika.

Ovako su stvarno komponente spojene u projektu dok je još na stolu i izradi:





Nakon konfiguriranja, uploada Python koda, lokalnog testiranja i pakiranja u malo vlastito kućište ovako moj projekt izgleda kad se nalazi u autu priključen na USB, a GPS uređaj je smješten ispod stražnjeg stakla radi boljeg prijema satelita:



Samo mini kućište sam izradio iz kartona pa se može preuzeti, isprintati i izrezati, a odgovara dimenzijama mojih korištenih komponenti.

[](/resources/RasPiGPS_cardboard.pdf)

Nakon što su komponente spojene, prije programiranja potrebno je Raspberry Pi konfigurirati.

## Inicijalno konfiguriranje Raspberry Pi-ja

Na Raspberry Pi-ju koji će se koristiti već mora biti instaliran Raspberry Pi OS, njega sam još od prije instalirao preko Raspberry Pi Imagera pa nije obuhvaćeno tutorialom. Također je na njemu prilikom instalacije kreiran i **pi** user s passwordom. Sam Raspberry inače ne koristim kad je spojen na monitor nego se spajam i konfiguriram u headless modu. To može samo malo komplicirati rad u početku. Bitno mu je složiti na koji se Wi-Fi spaja i koja će mu biti fiksna IP adresa.

Kako bi se moglo na njega spajati preko kućnog Wi-Fija prvo je potrebno na njegovoj SD kartici u rootu kreirati prazan file naziva **ssh** bez ekstenzije:



Također na SD kartici u rootu kreirati file točnog naziva **wpa_supplicant.conf** u kojem će se popuniti podaci za spajanje na Wi-Fi. Sadržaj samog file treba biti:
```sh
country=YOUR_COUNTRY_CODE
ctrl_interface=DIR=/var/run/wpa_supplicant GROUP=netdev
update_config=1
network={
    ssid="YOUR_WIFI_SSID"
    psk="YOUR_WIFI_PASSWORD"
    key_mgmt=WPA-PSK
}
```

Pod **YOUR_COUNTRY_CODE** staviti oznaku države (meni HR), pod **YOUR_WIFI_SSID** staviti SSID kućnog Wi-Fija i u **YOUR_WIFI_PASSWORD** staviti password mreže. Naravno ovdje je očito kako sigurnost nije na razini, ali barem će se Raspberry prilikom bootanja spojiti na mrežu. Sljedeća je stvar nakon što se boota pronaći njegov IP koji je dobio na mreži što se može pronaći najčešće spajanjem i provjerom na kućnom routeru.

Idući je korak spojiti se preko njegove IP adrese koristeći **Putty**, jednostavno unese se SSH konekcija s IP adresom Raspberry Pi-ja pa kad zatraži unese se username i password. Nakon spajanja dobije se odmah shell:



Iz shella dalje treba pokrenuti konfiguraciju Raspberry Pi OS-a:
```sh
sudo raspi-config
```

Dobije se ekran Configuration Tool i preko njega obavezno postaviti autologin s userom **pi** (postavio defaultnog usera) radi kasnijeg automatskog pokretanja Python skripte projekta:



Također obavezno treba omogućiti SSH server:



Nakon izlaska iz raspi-config potrebno je postaviti statičku IP adresu kako ne bi morali svaki put tražiti koji je IP kad se Raspberry spoji na router. Za to se editira file **/etc/dhcpcd.conf**, od samih editora kroz shell koristim najviše **pico**:
```sh
pico /etc/dhcpcd.conf
```

U fileu je potrebno doći do ovog dijela u kojem se konfigurira statička IP adresa i inicijalno su sve linije u fileu zakomentirane s **#**. Linije kao u primjeru otkomentirati i izmijeniti prema adresi routera i željenoj fiksnoj IP adresi:
```sh
# Example static IP configuration:
interface eth0
static ip_address=<YOUR_RASPBERRY_IP>/24
#static ip6_address=fd51:42f8:caae:d92e::ff/64
static routers=<YOUR_ROUTER_IP>
static domain_name_servers=<YOUR_ROUTER_IP> 8.8.8.8
```
Pod **<YOUR_RASPBERRY_IP>** staviti željenu fiksnu adresu, može biti i ona pod kojom se prvi put automatski Raspberry spojio na router, a pod **<YOUR_ROUTER_IP>** staviti IP adresu routera, npr. neki automatski imaju 192.168.0.1 i ta adresa se ne mijenja. Promjene spremiti i izaći iz editora.

Nakon promjena restartati Raspberry:
```sh
sudo shutdown -r now
```

Za upload i download fileova (Python koda, GPX fileova) na Raspberryjevoj SD kartici dok je na mreži najbolje i najpraktičnije je koristiti FTP protokol i neki besplatni klijent kao što je npr. FileZilla. Zato kroz shell treba instalirati i FTP server:
```sh
sudo apt install vsftpd
```

Nakon instalacije slijedi konfiguracija FTP servera editiranjem filea **/etc/vsftpd.conf**:
```sh
sudo pico /etc/vsftpd.conf
```

U fileu kada se pronađu ove zakomentirane linije treba ih otkomentirati brisanjem **#**
```sh
#write_enable=YES
#local_umask=022
#anon_upload_enable=YES
```

Na kraj filea dodati sljedeće linije:
```sh
user_sub_token=$USER
local_root=/home/$USER/FTP
```

Spremiti promjene, izaći iz editora te kroz shell kreirati FTP share direktorij **FTP/share** u home direktoriju usera i dodati sva prava userima:
```sh
mkdir -p /home/pi/FTP/share
chmod 777 /home/pi/FTP/share
```

Restartai FTP deamon:
```sh
sudo service vsftpd restart
```

Ako je sve uspješno odrađeno može se spojiti na Raspberry preko nekog FTP klijenta.

## Raspberry Pi uparivanje i spajanje Bluetooth GPS modula

Nakon inicijalne konfiguracije slijedi provjera i uparivanje GPS modula s Raspberry Pi te je ovaj korak jako bitan za dalje. Inače po bootu Raspberryja pokreće se i Bluetooth servis pa se status servisa može provjeriti preko shell naredbe:
```sh
systemctl status bluetooth
```

Očekivan je rezultat aktivan Bluetooth servis kao u ovom primjeru:
```sh
● bluetooth.service - Bluetooth service
     Loaded: loaded (/lib/systemd/system/bluetooth.service; enabled; vendor pre>
     Active: active (running) since Mon 2023-11-06 20:23:24 CET; 6 days ago
       Docs: man:bluetoothd(8)
   Main PID: 451 (bluetoothd)
     Status: "Running"
      Tasks: 1 (limit: 724)
        CPU: 327ms
     CGroup: /system.slice/bluetooth.service
             └─451 /usr/libexec/bluetooth/bluetoothd
```

Nakon što smo provjerili i potvrdili kako je servis aktivan potrebno je pokrenuti skeniranje Bluetooth uređaja u blizini. Naravno prije toga mora se upaliti vanjski Bluetooth GPS uređaj. Pronalaženje uređaja u blizini kroz shell:
```sh
hcitool scan
```

Rezultat skeniranja trebao bi biti lista Bluetooth uređaja s njihovim adresama i nazivima koji su vidljivi, npr.:
```sh
pi@raspberrypi:~ $ hcitool scan
Scanning ...
        00:02:78:19:70:30       HI-406BT
        4C:31:2D:73:88:88       MiTV-AYFR0
```

Korištenje **hcitool** je zapravo opcionalno (dobro posluži za kontrolu) pošto ću u nastavku za skeniranje i uparivanje koristit interaktivni tool **bluetoothctl** koji se pokreće kroz shell:
```sh
bluetoothctl
```

Nakon pokretanja pojavit će se njegov interaktivni shell kroz koji se upravlja uređajima:
```sh
Agent registered
[CHG] Controller B8:27:EB:F6:C0:3F Pairable: yes
[bluetooth]#
```

Prvo "upaliti" Bluetooth na samom toolu:
```sh
[bluetooth]# power on
Changing power on succeeded
```

Registrirati njegovog agenta:
```sh
[bluetooth]# agent on
Agent is already registered
```

Prebaciti na default agenta:
```sh
[bluetooth]# default-agent
Default agent request successful
```

Gornji koraci bili su "fire and forget" jer se samo oslanjam na metode koje provjereno rade. Nakon toga slijedi skeniranje okolnih uređaja i praćenje koji se pojavljuju kao rezultat (počet će se pojavljivati oni koji su vidljivi i kroz prethodno korištenje **hcitool**):
```sh
[bluetooth]# scan on
Discovery started
[CHG] Controller B8:27:EB:F6:C0:3F Discovering: yes
[NEW] Device DB:93:F3:DA:E4:C0 vívoactive3
[NEW] Device 00:02:78:19:70:30 00-02-78-19-70-30
[CHG] Device 00:02:78:19:70:30 LegacyPairing: no
[CHG] Device 00:02:78:19:70:30 Name: HI-406BT
[CHG] Device 00:02:78:19:70:30 Alias: HI-406BT
[CHG] Device 00:02:78:19:70:30 LegacyPairing: yes
```

Iz gornjeg rezultata što vrati tool potrebno je pronaći adresu Bluetooth GPS modula prema njegovom imenu i dobro je zapamtiti pošto će se koristiti više puta kroz tutorial. Ključno je detektirati koji GPS modul koristite pošto se svaki drugačije predstavlja. U mom primjeru iz korištenih komponenti koje koristim pronašao sam adresu 00:02:78:19:70:30 koja odgovara imenu HI-406BT. Tako i u vašem slučaju pronađite koja adresa odgovara te uparite s naredbom **pair** iza koje slijedi adresa, ovo je moj primjer:
```sh
[bluetooth]# pair 00:02:78:19:70:30
Attempting to pair with 00:02:78:19:70:30
[CHG] Device 00:02:78:19:70:30 Connected: yes
Request PIN code
[agent] Enter PIN code: 0000
[DEL] Device DB:93:F3:DA:E4:C0 vívoactive3
[CHG] Device 00:02:78:19:70:30 UUIDs: 00001101-0000-1000-8000-00805f9b34fb
[CHG] Device 00:02:78:19:70:30 ServicesResolved: yes
[CHG] Device 00:02:78:19:70:30 Paired: yes
Pairing successful
[CHG] Device 00:02:78:19:70:30 ServicesResolved: no
[CHG] Device 00:02:78:19:70:30 Connected: no
```

Odmah po pokušaju uparivanja kao što je gore vidljivo tražit će vas unos **PIN** koda za uparivanje, moj primjer i puno njih po defaultu imaju **0000**. Ako je sve prošlo uspješno vidjet ćete poruku **Pairing successful**. Prilikom uparivanja moguće je dobiti i ovakav tip greške:
```sh
[bluetooth]# pair 00:02:78:19:70:30
Attempting to pair with 00:02:78:19:70:30
Failed to pair: org.bluez.Error.AlreadyExists
```

> :warning: U tom slučaju najčešće je problem što je uređaj već na nešto povezan i u korištenju pa ga potrebno odspojiti iz konekcije s tim nekim drugim uređajem. Nakon toga ponoviti gornje korake. Ako ni to ne pomogne, može pomoći restart Bluetooth servisa.

Ako je do sada prošlo sve ispravno moguće je dobiti info o uređaju i statusu prema njegovoj adresi:
```sh
[bluetooth]# info 00:02:78:19:70:30
Device 00:02:78:19:70:30 (public)
        Name: HI-406BT
        Alias: HI-406BT
        Class: 0x00001f00
        Paired: yes
        Trusted: no
        Blocked: no
        Connected: no
        LegacyPairing: yes
        UUID: Serial Port               (00001101-0000-1000-8000-00805f9b34fb)
        RSSI: -35
```

Nadalje, mogu se vidjeti svi upareni uređaji, najvažnije vidjeti GPS modul koji će se koristiti u projektu:
```sh
[bluetooth]# paired-devices
Device 00:02:78:19:70:30 HI-406BT
```

Na kraju pošto je sve prošlo ok treba izaći iz **bluetoothctl** toola jer više neće biti potreban:
```sh
[bluetooth]# exit
```

Idući korak je tool **rfcomm** koji se također koristi u Bluetooth konfiguraciji kroz shell:
```sh
rfcomm
```

Rezultat će biti adresa i status **RFCOMM** kanala na koji je spojen Bluetooth uređaj kao što je moj primjer:
```sh
rfcomm1: 00:02:78:19:70:30 channel 1 closed
```

Bitno je zapamtiti iz rezultata **rfcomm1** pošto će se koristiti u nastavku kao dio naredbe. Za spajanje na uređaj kroz shell potrebno je onda kombinirati **/dev/rfcomm1** i adresu uređaja iz prethodnih koraka:
```sh
rfcomm bind /dev/rfcomm1 00:02:78:19:70:30
```

> :warning:  Ako nemate prava pojavit će se sljedeća greška:

**Can't create device: Operation not permitted**

Rješenje je koristiti **sudo** za sam poziv naredbe:
```sh
sudo rfcomm bind /dev/rfcomm1 00:02:78:19:70:30
```

Ako smo do sada sve u ovim koracima dobro proveli, što znači već smo uređaj uparili i koristimo ga dobit ćemo sljedeću poruku koja je zapravo ok:
**Can't create device: Address already in use**

Izgleda kao upozorenje ili greška, ali je rezultat prethodnih alata koji su se koristili. Kasnije u nastavku ovakvo bindanje kroz **rfcomm1** će se iskoristiti u Python skripti.

## Python komunikacija s Bluetooth GPS modulom

Sada je na redu pisanje prvog Python programa za komunikaciju s Bluetooth GPS modulom. Minimalna verzija Pythona trebala bi biti 3.5, u mom slučaju je korištena 3.9.2, ali uvijek je dobro koristiti što višu verziju. Pošto je komunikacija preko Bluetootha serijska, prvo kroz shell provjeriti postoji li instaliran Python library **pyserial** koji će se koristiti pa je provjera:
```sh
pip3 list | grep pyserial
```

Ako gornja provjera ne vrati postojanje libraryja, potrebno ga je instalirati (ako javi grešku kako nema prava prebaciti se na **pi** usera sa **su pi**):
```sh
pip3 install pyserial
```

Vrijeme je za kreiranje novog Python filea **raspi-gps.py** koji će čitati serijsku komunikaciju i ispisivati što smisleno dobije. Serijska komunikacija čita preko porta koji se nalazi na deviceu **/dev/rfcomm1** što odgovara prethodnom poglavlju. Bitno je naglasiti kako će se taj port koristiti u nastavku, a također su bitni odrađeni koraci samog spajanja na Bluetooth iz prethodnog poglavlja. Za ovu prvu skriptu obavezno je prvo se spojiti na GPS modul prije pokretanja (pogledati prethodno korištenje **rfcomm bind**). U beskonačnoj petlji se pokušava pročitati znak na serijskom portu sve dok se ne dođe do **'\r'** kao kraj poruke i takva se ispiše. Source kod prve iteracije spajanja na GPS modul i serijske komunikacije:
```python
import serial

sr = serial.Serial('/dev/rfcomm1', timeout=2)
line = ''

while True:
  chr = sr.read().decode('utf-8')
  if chr == '\r':
    print(line)
    line = ''
  else:
    line = line + chr
```

Nakon malo proučavanja source koda pokrenuti ga kroz shell:
```sh
python3 raspi-gps.py
```

Ako je sve prošlo u redu od prethodnih koraka i kod pokretanja Python skripte nije bilo grešaka, trebale bi se uskoro pojavljivati kriptične linije slične kao što su u mom primjeru:
```sh
$GPVTG,202.93,T,,M,0.05,N,0.1,K,N*0C

$GPGGA,165941.553,4553.9397,N,01650.9875,E,1,03,2.6,-41.4,M,41.4,M,,0000*49

$GPRMC,165941.553,A,4553.9397,N,01650.9875,E,0.10,216.49,130923,,,A*62

$GPVTG,216.49,T,,M,0.10,N,0.2,K,N*09

$GPGGA,165942.553,4553.9396,N,01650.9875,E,1,03,2.6,-41.4,M,41.4,M,,0000*4B

$GPRMC,165942.553,A,4553.9396,N,01650.9875,E,0.09,252.51,130923,,,A*61

$GPVTG,252.51,T,,M,0.09,N,0.2,K,N*08

$GPGGA,165943.553,4553.9396,N,01650.9874,E,1,03,2.6,-41.4,M,41.4,M,,0000*4B

$GPRMC,165943.553,A,4553.9396,N,01650.9874,E,0.10,215.45,130923,,,A*6F

$GPVTG,215.45,T,,M,0.10,N,0.2,K,N*06
```

Ovo izgleda potpuno ispravno i radi se o **NMEA** podacima koji dolaze iz komunikacije s GPS modulom. U nastavku ćemo se pozabavit njihovim dešifriranjem.

Ukoliko se kod pokretanja pojavila neka greška u bindanju GPS modula i vidljivo je kao ispad Pythona znači samo kako je potrebno prije pokretanja iz shella ponovno pokrenuti bindanje. Kao i u prethodnim koracima pokrenuti **rfcomm bind** s adresom uređaja (dalje ću umjesto adrese koristiti **<YOUR_BLUETOOTH_MAC_ADDRESS>**) i provjerite status:
```sh
sudo rfcomm bind /dev/rfcomm1 <YOUR_BLUETOOTH_MAC_ADDRESS>
rfcomm
```

Kako korak bindanja ne bi morali ponavljati prilikom svakog pokretanja Raspberry Pi-ja i provjeravali status prije pokretanja Python skripte, dodao sam poziv bindanja odmah u skriptu. Time će se izvršiti kao poziv OS naredbe prilikom svakog pokretanja ove skripte:
```python
import os
import serial
import sys
import time

try:
  fp = os.popen('sudo rfcomm bind /dev/rfcomm1 <YOUR_BLUETOOTH_MAC_ADDRESS>')
  time.sleep(2)
  fp.close()
except:
  print(sys.exc_info())
  sys.exit(1)

try:
  sr = serial.Serial('/dev/rfcomm1', timeout=2)
except:
  sys.exit(1)

line = ''

while True:
  try:
    chr = sr.read().decode('utf-8')
    if chr == '\r':
      print(line)
      line = ''
    else:
      line = line + chr
  except:      
    sys.exit(1)
```

Ponovno pokrenuti kroz shell:
```sh
python3 raspi-gps.py
```

Rezultat bi trebao biti isti, pojavljivat će se **NMEA** podaci GPS modula i manje treba voditi brigu o spajanju na modul, dovoljno ga upaliti i već nakon toga može se pokrenuti Python skripta koja će se njim početi komunicirati.

## GPS kodovi

**NMEA** (National Marine Electronics Association) je po imenu udruženje, a ovdje je bitna **NMEA-0183** specifikacija za komunikaciju prvenstveno namijenjena nautičkoj elektronici. Od toga najvažnije je što se koristi kao standard komunikacije GPS uređaja. Eksterni GPS uređaji preuzimaju signal s vidljivih satelita i uobličavaju ga u NMEA podatke koje dalje šalju kao u našem slučaju putem Bluetooth serijske komunikacije. Sami podaci koji se šalju sadrže identifikator trackera (GPS, Galileo, GLONASS, BeiDou), skupinu poruke koja se šalje i podatke koji odgovaraju skupini. Detalji sa skupinama i sadržaju poruka može se vidjeti na linku [NMEA Sentences](https://receiverhelp.trimble.com/alloy-gnss/en-us/NMEA-0183messages_MessageOverview.html).

Svaka poruka koja se zaprimi (NMEA sentence) počinje s **$** i oznakom trackera pa tako iz gornjeg primjera dolazi **$GP** što je oznaka za **GPS**. Ako vaš modul podržava i ostale sustave mogli bi dobiti početak poruke s npr. $GA za Galileo. Dalje se orijentiram na GPS pa dekodiram poruke koje počinju s **$GP**. Nakon oznake trackera dolazi skupina kojoj pripada poruka i za projekt, a i inače najvažnije su mi **GGA - Global Positioning System Fix Data** i **VTG - Track made good and Ground speed**.  GGA u podacima sadrži meni bitne: zemljopisnu širinu, dužinu, visinu i orijentaciju, ostale neću koristiti. VTG mi je zanimljiv samo radi očitanja brzine, ostale ne koristim.

Potrebne podatke sam ekstrahirao prema grupi i poziciji unutar poruke, za što mi je pomogla dokumentacija NMEA poruka, a dalje je stvar prezentacije podataka. Ovdje je izazov što je vrijednost pozicije zemljopisne širine i dužine malo drugačija od očekivanja pa je potrebno pretvoriti iz NMEA formatiranog podatka (format je (d)ddmm.mmmm gdje je **d** stupanj, a **m** minuta) u decimalni. Tu mi je za potvrdu konverzije morao malo pomoći jedan članak na [Stack Overflow](https://stackoverflow.com/questions/36254363/how-to-convert-latitude-and-longitude-of-nmea-format-data-to-decimal) pa sam u Pythonu kreirao i funkciju za konverziju.

Gornji Python program sam prema tome nadogradio. Pročitanu poruku s GPS, odnosno NMEA kodovima ekstraktam i provjeravam sadrži li potrebne grupe GGA i VTG te iz njih uzimam potrebne vrijednosti. Za prikaz pozicije dodatno konvertiram vrijednost u stupnjeve i dodajem pročitanu orijentaciju. Sada tako nadograđen i uljepšan Python kod izgleda ovako:
```python
import math
import os
import serial
import sys
import time

def nmeaToDeg(v):
  y, x = math.modf(v / 100)
  y = (y * 10) / 6
  return x + y

try:
  fp = os.popen('sudo rfcomm bind /dev/rfcomm1 <YOUR_BLUETOOTH_MAC_ADDRESS>')
  time.sleep(2)
  fp.close()
except:
  print(sys.exc_info())
  sys.exit(1)

try:
  sr = serial.Serial('/dev/rfcomm1', timeout=2)
except:
  sys.exit(1)

line = ''

while True:
  try:
    chr = sr.read().decode('utf-8')
    if chr == '\r':
      parts = line.replace('\n', '').split(',')

      try:
        # GGA - Global Positioning System Fix Data
        if parts[0] == '$GPGGA':
          latitude = nmeaToDeg(float(parts[2]))
          latitudeDirection = parts[3]
          longitude = nmeaToDeg(float(parts[4]))
          longitudeDirection = parts[5]
          print('Latitude / longitude: %s %s, %s %s' % 
            (latitude, latitudeDirection, longitude, longitudeDirection))
          elevation = float(parts[9])
          print('Elevation: %s m' % (elevation))

        # VTG - Track made good and Ground speed
        if parts[0] == '$GPVTG':
          speed = float(parts[7])
          print('Speed: %s km/h' % (speed))
      except:
        None

      line = ''
    else:
      line = line + chr
  except:
    print(sys.exc_info())
    sys.exit(1)
```

Ponovno pokrenuti kroz shell:
```sh
python3 raspi-gps.py
```

Rezultat bi trebao biti formatiran ispis trenutne pročitane GPS pozicije, visine i brzine ako se ona uspješno pročita i mijenja.

## Kreiranje GPX filea

Nakon pokretanja i testiranja ovog programa slijedi zapisivanje GPS pozicija u file, konkretno koristit ćemo **GPX** format. **GPX** ([GPS Exchange Format](https://en.wikipedia.org/wiki/GPS_Exchange_Format)) je XML schema za zapis GPS podataka radi korištenja u drugim aplikacijama, a u ovom tutorialu koristit ćemo ga za zapisivanje staze (track). Tako rezultira tracking našeg Raspberry Pi uređaja. Pri pokretanju će se uvijek kreirati novi jedinstveni **.gpx** file u koji će se ukoliko se promijeni pozicija nakon 10 sekundi zapisivati nova točka staze. Razlog zapisivanja samo promjene lokacije i to ako se događa nakon 10 sekundi je smanjenje samog filea, nema potrebe istu poziciju zapisivati u file ili baš svaku najmanju promjenu. Tim parametrima se može manipulirati, samo malo treba modificirati skriptu.

Za kreiranje **GPX** formata u Pythonu koristit ćemo library **gpxpy** - [GPX File Parser](https://pypi.org/project/gpxpy/). Prvo je potrebna provjera instalacije libraryja:
```sh
pip3 list | grep gpxpy
```

Ako gornja provjera ne vrati postojanje libraryja (inicijalno nije instaliran), potrebno ga je instalirati (ako javi grešku kako nema prava prebaciti se na **pi** usera sa **su pi**):
```sh
pip3 install gpxpy
```

Korištenje libraryja sastoji se od kreiranja objekta i pripadnih staza (trackova) i segmenata koji sadrže točke. Točke su pojedina GPS pozicija koju ćemo zapisati u objekt koji rezultira spremanjem u GPX file. Pošto se pozicija u GPX objektu ne može zapisati točno kako smo je pročitali iz komunikacije, odnosno NMEA poruke, potrebno ju je malo prilagoditi. Jedan oblik prilagodbe je sam format ispisa što sam napravio u prethodnoj Python skripti pa ću to iskoristiti, a dalje slijedi još jedan dodatak. Naime, orijentacija pozicije (N, S, E, W) je samostalna u NMEA poruci, ali je u GPX formatu sadržana u zemljopisnoj širini i dužini. Zbog toga orijentacije S i W množim s -1 kako bi ih pretvorio u GPX format. Također bitna stvar u zapisivanju je i točno vrijeme koje mora biti u **ISO 8601** formatu.

U doljnjem kodu može se vidjeti kako skripta ne zapisuje brzinu u GPX objekt. Razlog tome je što se po defaultu koristi GPX verzija 1.1 koja ne sadržava brzinu. Ukoliko se želi zapisati i brzina (za auto entuzijaste), potrebno je koristiti verziju GPX 1.0. To bi bila manja prilagodba u tome što se brzina treba dodati na kraj parametara poziva ```gpxpy.gpx.GPXTrackPoint``` kao ```speed = speed``` i poziv ```gpx.to_xml()``` zamijeniti s ```gpx.to_xml(version="1.0")``` dok ostalo ostaje isto. Nekome može biti dodatan izazov i što se brzina čita iz VTG poruke, a ostalo iz GGA poruke prema kojoj se trenutno i zapisuje.

Dodatna sitna fukcionalnost koju sam ugradio nalazi se na početku izvršavanja Python skripte, a odnosi se na čitanje argumenata s kojima smo je pozvali. Dobro može doći kod pripreme uparivanja i početka komunikacije s GPS modulom. Naime, ako se kao argument proslijedi neki broj, skripta će pauzirati toliko sekundi prije nego nastavi dalje s radom. Ova funkcionalnost će se iskoristiti u idućem poglavlju.

Nova iteracija Python koda nakon dodavanja opisanih funkcionalnosti sada izgleda ovako:
```python
import datetime
import gpxpy
import math
import os
import serial
import sys
import time

def nmeaToDeg(v):
  y, x = math.modf(v / 100)
  y = (y * 10) / 6
  return x + y

# from argument set sleep
if len(sys.argv) > 1:
  time.sleep(int(sys.argv[1]))

try:
  fp = os.popen('sudo rfcomm bind /dev/rfcomm1 <YOUR_BLUETOOTH_MAC_ADDRESS>')
  time.sleep(2)
  fp.close()
except:
  print(sys.exc_info())
  sys.exit(1)

try:
  sr = serial.Serial('/dev/rfcomm1', timeout=2)
except:
  sys.exit(1)

line = ''

# GPX object, track, segment
gpx = gpxpy.gpx.GPX()
gpx.name = 'Raspberry Pi GPS'
gpx.description = 'GPS track'
gpx_track = gpxpy.gpx.GPXTrack()
gpx.tracks.append(gpx_track)
gpx_segment = gpxpy.gpx.GPXTrackSegment()
gpx_track.segments.append(gpx_segment)

t0 = None
lat0 = 0
lon0 = 0
file_name = datetime.datetime.now().strftime('%Y%m%dT%H%M%S') + '.gpx'

while True:
  try:
    chr = sr.read().decode('utf-8')
    if chr == '\r':
      parts = line.replace('\n', '').split(',')

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

        # VTG - Track made good and Ground speed
        if parts[0] == '$GPVTG':
          speed = float(parts[7])
          print('Speed: %s km/h' % (speed))
      except:
        None

      line = ''
    else:
      line = line + chr
  except:
    print(sys.exc_info())
    sys.exit(1)
```

Pokrenuti kroz shell:
```sh
python3 raspi-gps.py
```

Rezultat što se tiče samog ispisa trebao bi biti isti kao u prethodnom Python kodu, ali će se u istom folderu također kreirati **.gpx** file koji će se povećavati kako se bilježe promjene GPS pozicije.

## Automatsko pokretanje Python skripte

Sada je Python skripta već dovoljno kompletirana pa bi se mogla automatski pokretati svaki put nakon što se boota Raspberry Pi umjesto kao do sada ručnim pokretanjem. Ručno pokretanje je u redu kada se ovako doma programira i testira, ali finalno kada je u živom radu pokretanje mora biti automatsko i to što prije. Kako bi se dodalo automatsko pokretanje prilikom bootanja potrebno je editiranje filea **/etc/rc.local**, opet koristim pico: 
```sh
sudo pico /etc/rc.local
```

Potrebno se pozicionirati prije linije **exit 0** i dodati sljedeće linije:
```sh
cd /home/pi/FTP/share
sudo -u pi python3 raspi-gps.py 30 > log.txt 2>&1 &
```

U mom slučaju file izgleda ovako:



Ovom promjenom prvo se u izvođenju pozicioniramo u direktorij gdje se nalazi Python skripta. Nakon toga se pod userom **pi** (ovo je obavezno) pokreće Python skripta **raspi-gps.py** s parametrom čekanja od 30 sekundi (što bi trebalo biti dovoljno za podizanje svih servisa o kojima zavisi), output pokretanja skripte prosljeđuje se u log file **log.txt** kako bi se u njemu mogle vidjeti greške pokretanja, a na kraju cijelog reda obavezan je znak **&** kojim se tako pokrenut proces izvršava u backgroundu.

Parametar u pokretanju koji se odnosi na čekanje od 30 sekundi sam spomenuo u prethodnom poglavlju i odnosi se na ovaj dio koda Python skripte pa ako se se proslijedi neki drugi broj toliko će sekundi čekati na nastavak izvršavanja:
```python
# from argument set sleep
if len(sys.argv) > 1:
  time.sleep(int(sys.argv[1]))
```

Nakon spremanja promjene filea **/etc/rc.local** potrebno je restartati Raspberry Pi kroz shell:
```sh
sudo shutdown -r now
```
ili
```sh
sudo reboot
```

Time će se ako je sve prošlo ispravno automatski pokrenuti Python skripta. Ako je došlo do greške, ona je vidljiva u istom folderu u fileu **log.txt**.

Bitno je spomenuti i ako se nakon uspješnog pokretanja ponovno spajamo Puttyjem na Raspberry Pi te mijenjamo skriptu potrebno je prije ručnog pokretanja nove verzije kill-ati postojeći proces. Provjera pokrenute skripte kroz shell:
```sh
ps -fu pi | grep raspi-gps
```

Prema rezultatu pronaći ```<pid>``` aktivnog procesa te kroz shell pozvati ```kill <pid>``` tog procesa.

## Korištenje gumba i RGB LED-ice

Do sada je izrađena osnova GPS trackera koji se u ovom obliku može i sam koristiti, ali tada nema interakcije. Vrijeme je za upogoniti gumb koji je u ovom projektu jedini oblik interakcije zajedno s RGB LED signalizacijom rada Raspberry Pi-ja. U tu svrhu kreirat ćemo novi Python file **gpio_test.py** radi isprobavanja spojenog gumba i paljenja / gašenja RGB LED-ice u različitim bojama.

Način spajanja gumba i RGB LED-ice s Raspberry Pi-jem vidjeli smo još na početku u poglavlju [Komponente](#komponente). Komponente su spojene na Raspberry Pi pinove napona, uzemljenja i one koji se mogu koristiti za opću namjenu. Raspored pinova i koje su im namjene može se vidjeti na linku [Raspberry Pi Pinout](https://pinout.xyz/) ili kroz shell:
```sh
pinout
```

Izabrao sam pinove koji mi odgovaraju prema smještaju, u vlastitoj verziji projekta možete koristiti i neke druge uz izmjene u kodu. U narednoj skripti za testiranje koristit ću pin **GPIO3** za očitanje pritiska gumba, **GPIO17** za crveni pin, **GPIO22** za zeleni pin i **GPIO10** za plavi pin RGB LED-ice. Dodatno ću iskoristiti pin **GPIO27** kao naponski pin.

Za upravljanje GPIO pinovima koristit će se **gpiozero** interface koji bi već trebao biti instaliran u sklopu Pythona na Raspberry OS-u. Koriste se njegove klase Button, LED i RGBLED te svakoj od njih dodjeljuje rad s pojedinim pinom. Programiranje je relativno jednostavno i intuitivno, sastoji se od paljenja / gašenja pojedinih pinova ili očitanja stanja gumba na pinu. Source kod **gpio_test.py** za upravljanje gumbom i RGB LED-icom tako izgleda ovako:
```python
import datetime
from gpiozero import Button, LED, RGBLED
import time

button = Button(3) # GPIO3
led = RGBLED(red = 17, green = 22, blue = 10) # red GPIO17, green GPIO22, blue GPIO10
power = LED(27) # GPIO27

power.on()
led.color = (0, 1, 1)
print('red')
time.sleep(2)
led.color = (1, 0, 1)
print('green')
time.sleep(2)
led.color = (1, 1, 0)
print('blue')
time.sleep(2)
led.color = (1, 1, 1)

t0 = 0

while True:

  if button.is_pressed:
    print('pressed')
    t1 = datetime.datetime.now()
    if t0 == 0:
      t0 = t1
    if (t1 - t0).total_seconds() > 5:
      led.color = (0, 1, 1)
      print('red')
      time.sleep(1)
      led.color = (1, 1, 1)
      t0 = 0
    else:
      led.color = (0, 0, 1)
      print('yellow')
      time.sleep(1)
      led.color = (1, 1, 1)
  else:
    t0 = 0
    led.color = (1, 0, 1)
    print('green')
    time.sleep(1)
    led.color = (1, 1, 1)

  try:
    time.sleep(1)

  except:
    print(sys.exc_info())
    led.color = (0, 1, 1)
    print('red')
    time.sleep(2)
    led.color = (1, 1, 1)
    power.off()
    sys.exit(1)
```
[][def-gpio_test.py]

Nakon malo proučavanja source koda treba ga pokrenuti kroz shell:
```sh
python3 gpio_test.py
```

U inicijalizaciji se prvo dodjeljuju svakoj klasi pojedini pinovi. Odmah se na dvije sekunde RGB LED-ica treba upaliti crveno, zeleno pa plavo. Način korištenja klase RGBLED, odnosno puštanje napona na pojedini pin koji upravlja bojom kako je vidljivo u sourceu ovisi o korištenoj RGB LED-ici, a u mom primjeru koristim onu sa zajedničkom anodom (+). Nakon paljenja pojedine boje program provjerava stanje gumba, ako je pritisnut dulje od 5 sekundi RGB LED-ica će zasvijetlit crveno, kraće od toga će zasvijetlit žuto, a ako gumb nije pritisnut zasvijetlit će zeleno. I nakon jedne sekunde ide iduća iteracija petlje. Za svaki slučaj u testu statusi pritisnutog gumba i koja boja se pali se ispisuju prilikom izvođenja.

## Kompletiranje Python koda

U ovom poglavlju se dosadašnje Python skripte objedinjuju u finalni Python kod projekta koji će upravljati Bluetoothom, GPS modulom, gumbom i RGB LED-icom.

Osim toga iskoristit ću priliku neke postojeće funkcionalnosti izdvojiti u klase i dodati nove funkcije. Tako sam kreirao novu klasu **Color** kao enumeracija za paljenje pojedinih boja na RGB LED-ici. Kreiranje i zapisivanje rute izdvojio sam u novu klasu **Recorder**. Za ispade programa dodatno imam funkciju **terminate** i za gašenje Raspberry Pi-ja funkciju **shutdown**. Od novog većeg seta linija koda dodao sam detekciju pritiska gumba i ovisno o duljini pritiska mijenjaju se statusi početka ili kraja snimanja rute zajedno sa signalizacijom LED-icom te sam još dodao novu fukcionalnost gašenja cijelog Raspberry Pi-ja. Ispod source koda nalaze se i kraće upute.

Finalni ovako kompletiran **raspi-gps.py** sada izgleda ovako:
```python
import datetime
from enum import Enum
from gpiozero import Button, LED, RGBLED
import gpxpy
import math
import os
import serial
import sys
import time

class Color(Enum):
  RED = (0, 1, 1)
  GREEN = (1, 0, 1)
  BLUE = (1, 1, 0)
  NONE = (1, 1, 1)

class Recorder:
  def __init__(self):
    self.recording = False
    self.__file_name = datetime.datetime.now().strftime('%Y%m%dT%H%M%S') + '.gpx'
    # GPX object, track, segment
    self.__gpx = gpxpy.gpx.GPX()
    self.__gpx.name = 'Raspberry Pi GPS'
    self.__gpx.description = 'GPS track'
    self.__gpx_track = gpxpy.gpx.GPXTrack()
    self.__gpx.tracks.append(self.__gpx_track)
    self.__gpx_segment = gpxpy.gpx.GPXTrackSegment()
    self.__gpx_track.segments.append(self.__gpx_segment)

  def addPoint(self, latitude, longitude, elevation, time):
    self.__gpx_segment.points.append(gpxpy.gpx.GPXTrackPoint(
      latitude = latitude, 
      longitude = longitude, 
      elevation = elevation, 
      time = time))
    self.write()

  def write(self):
    file = open(self.__file_name, 'w')
    file.write(self.__gpx.to_xml())
    file.close()

def nmeaToDeg(v):
  y, x = math.modf(v / 100)
  y = (y * 10) / 6
  return x + y

def terminate():
  led.color = Color.RED.value
  time.sleep(2)
  led.color = Color.NONE.value
  power.off()
  sys.exit(1)

def shutdown():
  track.write()
  led.color = Color.NONE.value
  power.off()
  os.system('sudo shutdown now')

# button connected to GPIO3
button = Button(3)
# LED pins: red GPIO17, green GPIO22, blue GPIO10
led = RGBLED(red = 17, green = 22, blue = 10)
# power pin on GPIO27
power = LED(27)
power.on()
led.color = Color.BLUE.value

# from argument set sleep
if len(sys.argv) > 1:
  time.sleep(int(sys.argv[1]))

try:
  fp = os.popen('sudo rfcomm bind /dev/rfcomm1 <YOUR_BLUETOOTH_MAC_ADDRESS>')
  time.sleep(2)
  fp.close()
except:
  print(sys.exc_info())
  terminate()

try:
  sr = serial.Serial('/dev/rfcomm1', timeout=2)
except:
  terminate()

led.color = Color.NONE.value
line = ''

t0 = None
lat0 = 0
lon0 = 0
tb0 = None
statusChanged = False
track = Recorder()

while True:
  try:
    if button.is_pressed:
      tb1 = datetime.datetime.now()
      if tb0 == None:
        tb0 = tb1
      td = (tb1 - tb0).total_seconds()
      if td > 10:
        led.color = Color.RED.value
        time.sleep(2)
        shutdown()
      else:
        if td < 0.5:
          # green for start recording, red for stop
          if track.recording:
            led.color = Color.RED.value
          else:
            led.color = Color.GREEN.value
        else:
          if not statusChanged:
            statusChanged = True
            if track.recording:
              track.write()
              track.recording = False
            else:
              track = Recorder()
              track.recording = True
            led.color = Color.NONE.value
    else:
      if tb0 != None:
        tb0 = None
        statusChanged = False
        led.color = Color.NONE.value

    chr = sr.read().decode('utf-8')
    if chr == '\r':
      parts = line.replace('\n', '').split(',')

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

        # VTG - Track made good and Ground speed
        #if parts[0] == '$GPVTG':
        #  speed = float(parts[7])
        #  print('Speed: %s km/h' % (speed))
      except:
        led.color = Color.RED.value
        time.sleep(0.1)
        led.color = Color.NONE.value
        time.sleep(0.5)

      line = ''
    else:
      line = line + chr
  except:
    print(sys.exc_info())
    terminate()
```
[][def-raspi-gps.py]

Nakon malo proučavanja source koda treba ga pokrenuti kroz shell, ali sada zbog kompleksnosti dobro je kao novi korak prvo provjeriti sintaksu skripte:
```sh
python3 -m py_compile raspi-gps.py
python3 raspi-gps.py
```

Sada će program počet signalizirati svoj rad.

RGB LED-ica signalizira plavom bojom korak spajanja na GPS modul. Ako se tokom tog procesa dogodila neka pogreška zasvijetlit će crveno na 2 sekunde i program prestaje s radom. U tom slučaju nema druge nego pogledati u **FTP/share** folderu log s greškom. Takve greške su trebale biti vidljive i ranije tokom testa. Inače ako je sve dobro prošlo po prethodnim koracima i zamijenjeno što je označeno u Python skripti prema tutorialu ne bi trebalo biti problema.

Kada je uspješno uparen GPS modul s Raspberryjem program povremeno odaje neke dodatne signale o radu. Prilikom snimanja rute ako se promijeni pozicija svakih 10 sekundi zasvijetlit će zeleno. Ako se nije skroz pozicionirao prema satelitima i ne očitava točno poziciju blinkat će crveno. Pritiskom gumba dok se ne snima ruta LED-ica će zasvijetlit zeleno. Dovoljno držati gumb 0,5 sekunde kako bi se pokrenulo snimanje rute. Suprotno, dok program snima rutu pritiskom gumba LED-ica će zasvijetliti crveno. Držanjem tako gumba 0,5 sekundi prestat će se snimati ruta. Zato je isti gumb u modu on/off pa će za pokretanje zasvijetliti LED-ica zeleno, a zaustavljanje crveno.

Svako snimanje kreira poseban **.gpx** file u folderu **FTP/share** koji se može downloadati i dalje otvoriti u nekom samostalnom softwareu kao što je npr. Google Earth radi vizualnog pregleda rute. Za sam kraj rada Python programa, ali i gašenje cijelog Raspberryja potrebno je držati pritisnut gumb 10 sekundi što će isto signalizirati crvenom LED-icom. Kada se želi ponovno pokrenuti, ponoviti cijeli gornji ciklus, odnosno fizički upaliti Raspberry.

I to su upute za korištenje. :smiley:

## Projekt u živom radu

Nakon testa cijelog sustava doma na stolu i PC-u vrijeme je za pravo korištenje u realnim uvjetima, u mom slučaju vožnji jednom rutom. Spajanjem Raspberryja na USB auta ili powerbank počinje se bootati i nakon toga odmah pokreće Python skriptu. Znači kad se boota Raspberry odmah upaliti i eksterni GPS modul kako bi se upario Bluetoothom te što prije pozicionirao prema vidljivim satelitima. Dalje je stvar trenutka kada palite i gasite snimanje rute putem gumba prema uputama iz prethodnog poglavlja.

Jedna moja tako snimljena ruta je u primjeru:

[][def-gpx-sample]

**.gpx** file sam otvorio u Google Earthu i slika je u nastavku. Inače je alat dovoljno intuitivan pa nakon učitavanja rute i njenog iscrtavanja prikazat će dodatne gumbe na svom sučelju.



## Off topic pojednostavljenje s manje komponenti

Ako se koristi kao u mom slučaju Raspberry Pi Zero W i sam projekt se želi još više pojednostavniti smanjenjem broja komponenti, mogla bi se iskoristiti interna LED-ica Raspberryja umjesto RGB LED-ice na eksperimentalnoj pločici. Korak dalje, ako se ne bi koristili otpornici i raducirao broj žica došli bi do samo spajanja gumba na Raspberry kao na ovom minimalnom dijagramu:

Fritzing dijagram - Raspberry Pi Zero W s minimumom komponenti

Izgleda asketski i izuzetno kompaktno, a paljenje i gašenje interne LED-ice moguće je s malo hacka pošto će se pozivati shell naredbe. Radi se o zapisivanju high (1) ili low (0) vrijednosti u datoteku **/sys/class/leds/mmc0/brightness** što nije izvedivo preko običnog usera pa ćemo koristiti **sudo**.

Paljenje interne LED-ice kroz shell:
```sh
sudo sh -c "echo 1 > /sys/class/leds/mmc0/brightness"
```
Gašenje interne LED-ice kroz shell:
```sh
sudo sh -c "echo 0 > /sys/class/leds/mmc0/brightness"
```
Ako ne uspije od prve samo treba ponovno pokrenuti naredbe kroz shell.

Kako upaliti i ugasiti internu LED-icu putem gumba, a isprogramirano kroz jednostavnu Python skriptu? U nastavku je implementacija koja poziva shell naredbe iz Pythona, prvo se isprobavaju pozivi spremanja high i low vrijednosti te nakon toga se prati pritisak gumba na pinu GPIO3. Držanjem gumba 5 sekundi upali se LED-ica, svijetli sekundu i nakon toga se ugasi.

Kreirati file **internal_led_test.py** sa source kodom:
```python
import datetime
from gpiozero import Button
import os
import time

button = Button(3) # GPIO3

os.system('sudo sh -c "echo 1 > /sys/class/leds/mmc0/brightness"')
time.sleep(2)
os.system('sudo sh -c "echo 0 > /sys/class/leds/mmc0/brightness"')

t0 = 0

while True:

  if button.is_pressed:
    print('pressed')
    t1 = datetime.datetime.now()
    if t0 == 0:
      t0 = t1
    if (t1 - t0).total_seconds() > 5:
      os.system('sudo sh -c "echo 1 > /sys/class/leds/mmc0/brightness"')
      time.sleep(1)
      os.system('sudo sh -c "echo 0 > /sys/class/leds/mmc0/brightness"')
      t0 = 0
  else:
    t0 = 0

  time.sleep(1)
```
[][def-internal_led_test.py]

Pokretanje Python skripte kroz shell:
```sh
python3 internal_led_test.py
```

Ako je sve ok, uz malo intervencije relativno lako možete samostalno doraditi **raspi-gps.py** kako bi Raspberry radio s internom LED-icom. :yum:

## Reference

- [Headless Raspberry Pi Setup](https://learn.sparkfun.com/tutorials/headless-raspberry-pi-setup/wifi-with-dhcp)
- [Raspberry Pi Configuration](https://www.raspberrypi.com/documentation/computers/configuration.html)
- [Raspberry Pi Hardware](https://www.raspberrypi.com/documentation/computers/raspberry-pi.html)
- [Raspberry Pi Pinout](https://pinout.xyz/)
- [NMEA Sentences](https://receiverhelp.trimble.com/alloy-gnss/en-us/NMEA-0183messages_MessageOverview.html)
- [GPS Exchange Format](https://en.wikipedia.org/wiki/GPS_Exchange_Format)
- [GPX File Parser](https://pypi.org/project/gpxpy/)
- [Physical Computing with Python](https://projects.raspberrypi.org/en/projects/physical-computing/0)

<!----------------------------------------------------------------------------------------------------------------->

[def-gpio_test.py]: /scripts/gpio_test.py
[def-raspi-gps.py]: /scripts/raspi-gps.py
[def-internal_led_test.py]: /scripts/internal_led_test.py
[def-gpx-sample]: /resources/20231026T195728.gpx

[Download Icon]: https://img.shields.io/badge/Download-37a779?style=for-the-badge&logoColor=white&logo=DocuSign
